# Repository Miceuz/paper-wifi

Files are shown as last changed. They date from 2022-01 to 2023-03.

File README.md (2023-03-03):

# Paper-WiFi

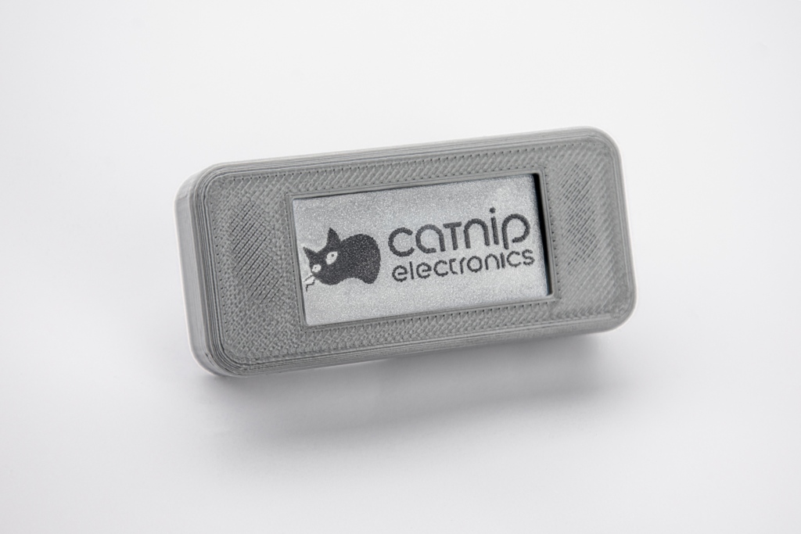
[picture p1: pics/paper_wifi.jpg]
Paper Wifi




Wifi-enabled e-paper display for I2C sensors. Arduino compatible software on Platformio. 3D printable case.

## Specifications

 * MCU: ESP32C3
 * Power supply: 2xAA, 3V
 * Sleep current: 38uA
 * Screen size: 2.13"
 * Display resolution: 212(H) × 104(V) pixels
 * Connectivity: I2C, UART over USB, UART
 * GPIO: 2 
 * Sensors: Temperature, Relative humidity
 * Temperature accuracy: 0.2°C typical
 * Relative humidity accuracy: 1.8% typical

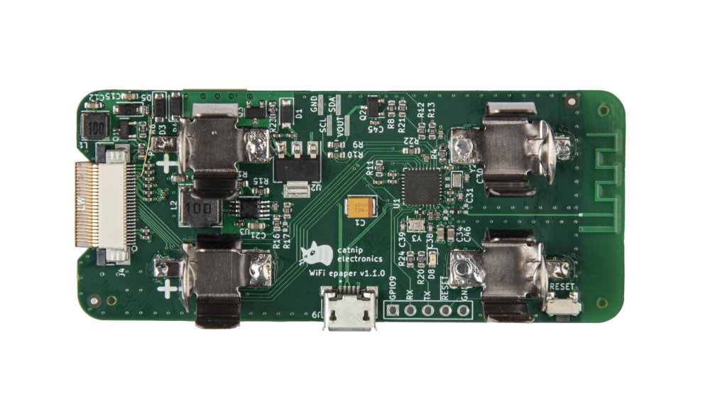
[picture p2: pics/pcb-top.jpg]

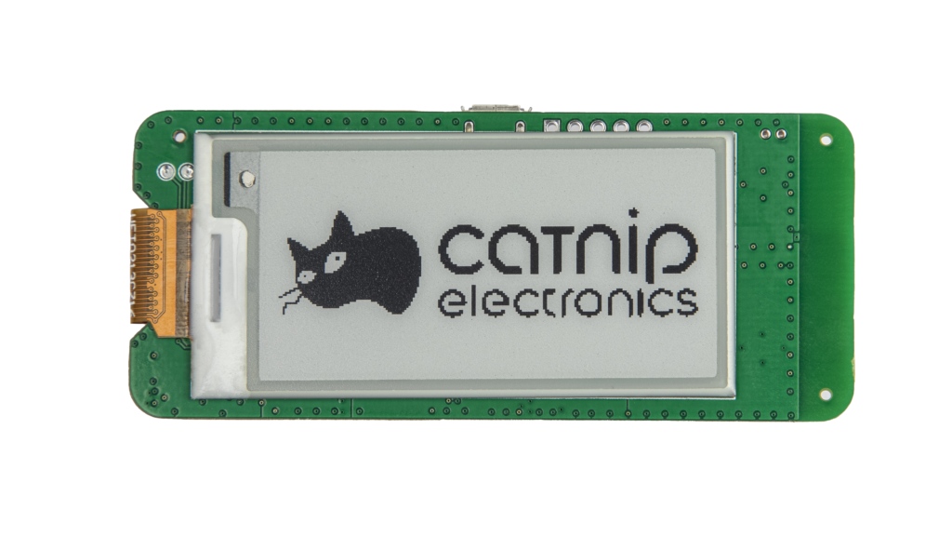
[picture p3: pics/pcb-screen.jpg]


## Programming instructions

Firmware build and upload process is managed by [Platformio](https://platformio.org). Most probably you will encounter the board in deep sleep in which it is not visible via USB. Jump GPIO9 to GND and reset the board to put it into bootloader mode. Run `pio run -t upload` to compile and upload firmware. Remove jumper and reset the board to run. If deep sleep is not used, board can be programmed without GPIO9 jumper.

## MQTT backend infrastructure

 * To quickly see your data piping in follow this guide: [Getting started with MQTT](https://github.com/Miceuz/paper-wifi/tree/main/tutorials/Getting%20started%20with%20MQTT)
 * To setup your own backend for data storage and display follow this guide: [docker-compose-mosquitto-influxdb-telegraf-grafana](https://github.com/Miceuz/docker-compose-mosquitto-influxdb-telegraf-grafana)

## Licence

[CERN Open Hardware Licence Version 2 - Strongly Reciprocal](https://ohwr.org/cern_ohl_s_v2.txt)

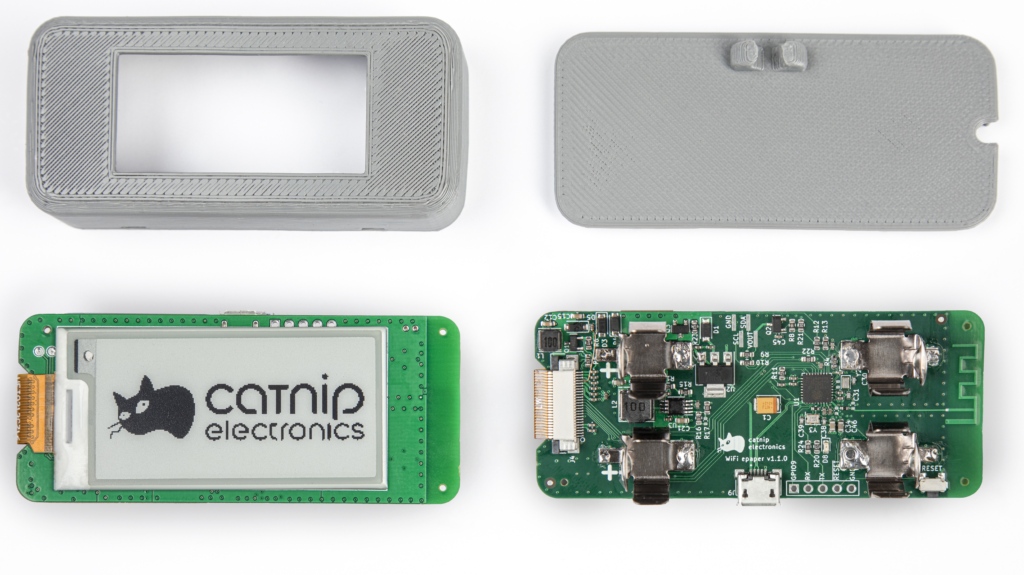
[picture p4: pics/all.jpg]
Paper Wifi internals


Open source
Made with KiCad
![Build with PlatformIO](https://img.shields.io/badge/build%20with-PlatformIO-orange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)


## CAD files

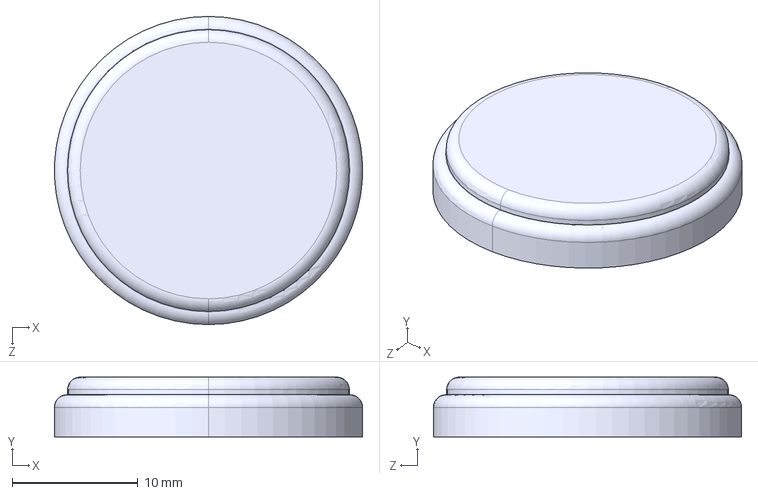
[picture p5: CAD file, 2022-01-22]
electronics/sensor-epaper/3d/User Library-CR 2450.STEP
24.5 x 4.75 x 24.5 mm

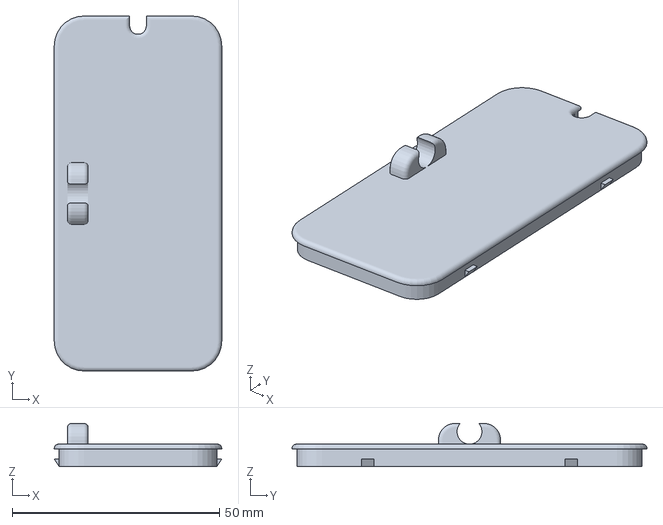
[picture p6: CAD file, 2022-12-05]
mechanical/enclosure-cover.3mf
40.4 x 85.6 x 10.4 mm

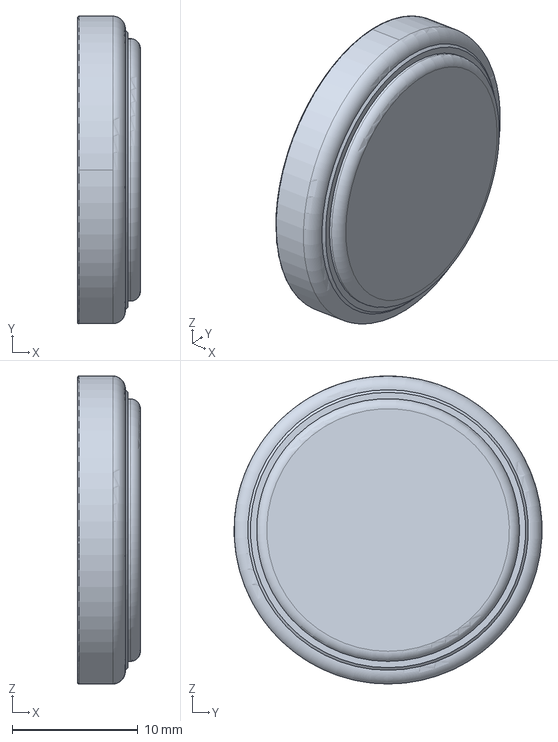
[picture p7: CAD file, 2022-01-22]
electronics/sensor-epaper/3d/battery-cr2450.stp
5.00 x 24.5 x 24.5 mm

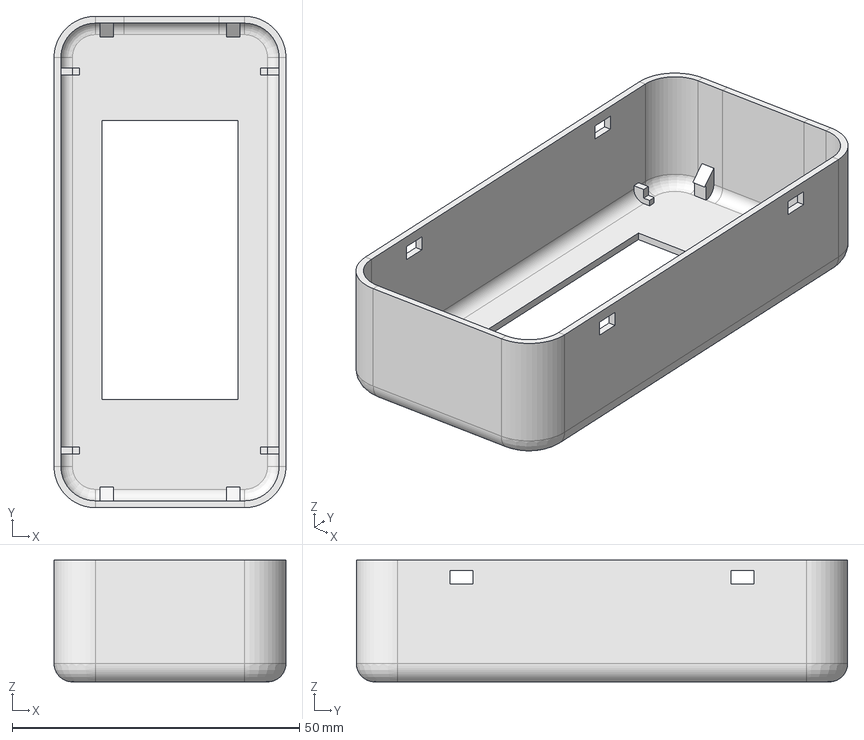
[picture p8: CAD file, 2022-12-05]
mechanical/enclosure.FCStd
40.4 x 85.6 x 21.2 mm

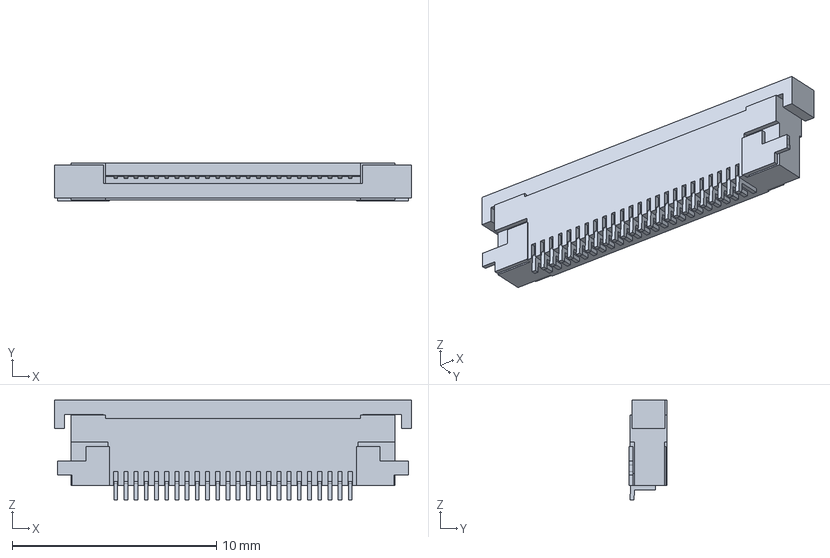
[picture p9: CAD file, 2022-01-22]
electronics/sensor-epaper/3d/ssfv24r_4stlf.stp
17.5 x 1.87 x 4.90 mm

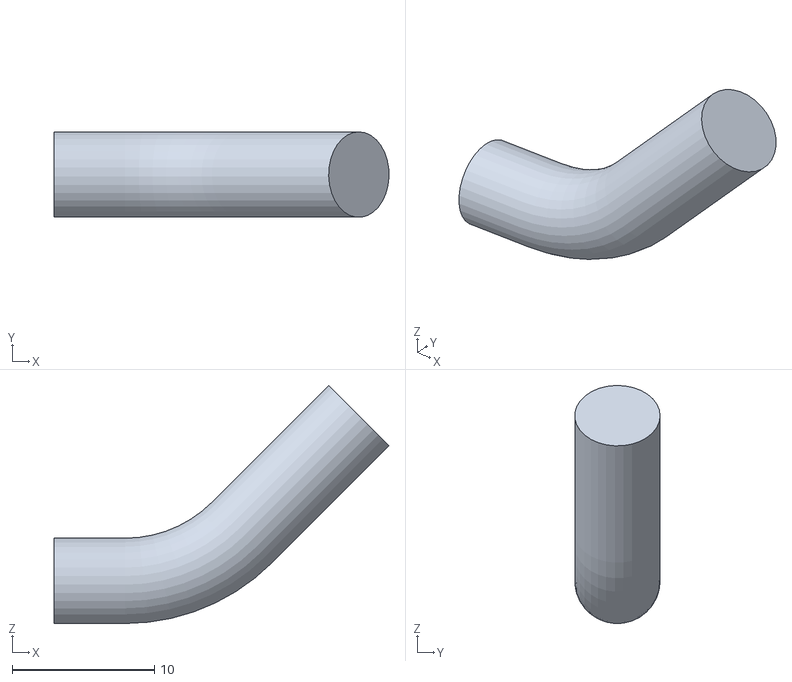
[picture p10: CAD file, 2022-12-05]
mechanical/enclosure-kronschtein.stl
23.5 x 5.99 x 16.7

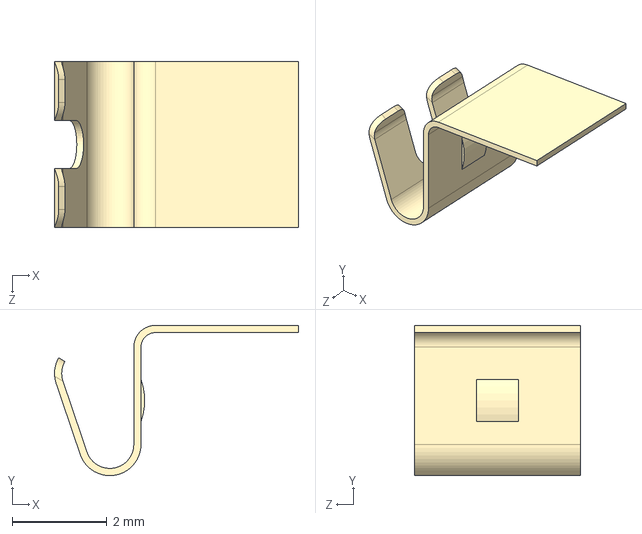
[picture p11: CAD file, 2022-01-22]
electronics/sensor-epaper/3d/keystone-PN110TR.STEP
5.16 x 3.17 x 3.51 mm

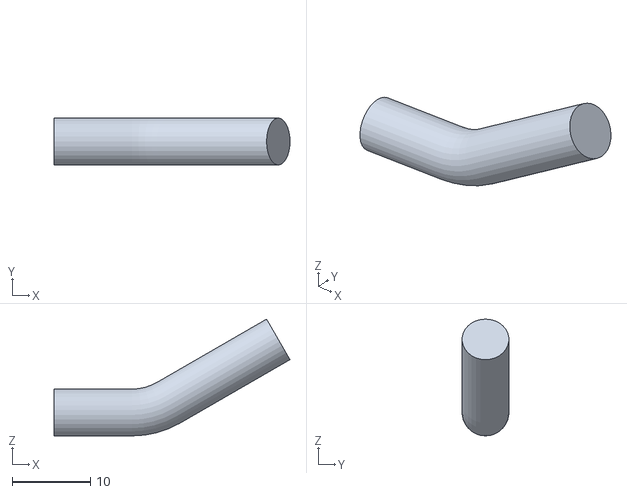
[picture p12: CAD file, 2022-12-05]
mechanical/enclosure-kronschtein1.stl
30.2 x 5.97 x 15.0

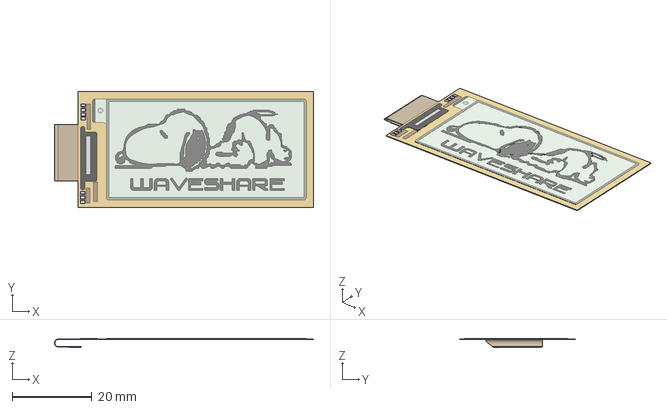
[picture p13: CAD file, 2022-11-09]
mechanical/Waveshare 2.13 (D) E-ink - Reverse Mount.stp
65.1 x 29.2 x 2.17 mm

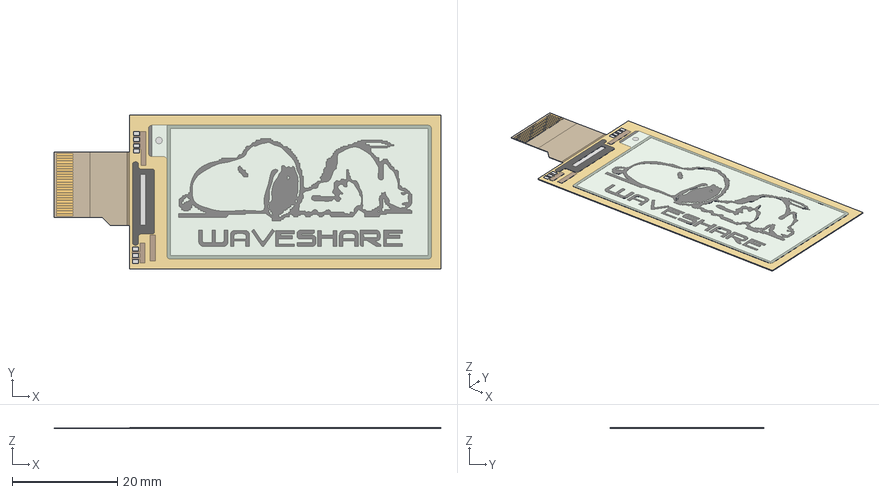
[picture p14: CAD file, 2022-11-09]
mechanical/Waveshare 2.13 (D) E-ink - Flat.stp
73.5 x 29.2 x 0.229 mm

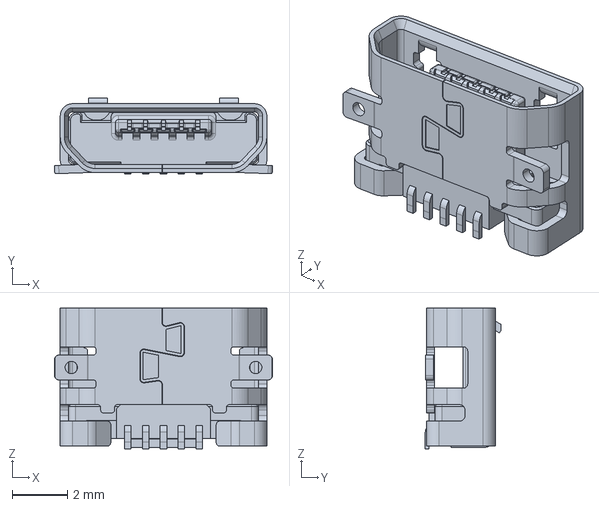
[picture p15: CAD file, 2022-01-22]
electronics/sensor-epaper/3d/10118192-002lfc.stp
7.91 x 2.77 x 5.10 mm

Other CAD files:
mechanical/enclosure-Body.3mf
mechanical/enclosure-Body.stl
mechanical/enclosure-cover.stl

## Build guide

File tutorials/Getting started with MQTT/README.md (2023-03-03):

# Getting your data via MQTT
This guide will allow you to see your data being sent via MQTT. Saving data to databases and displaying graphs is another story, but here we will concentrate on getting MQTT running.

## Listening to MQTT messages on your browser 
Open this page on your browser: http://www.emqx.io/online-mqtt-client

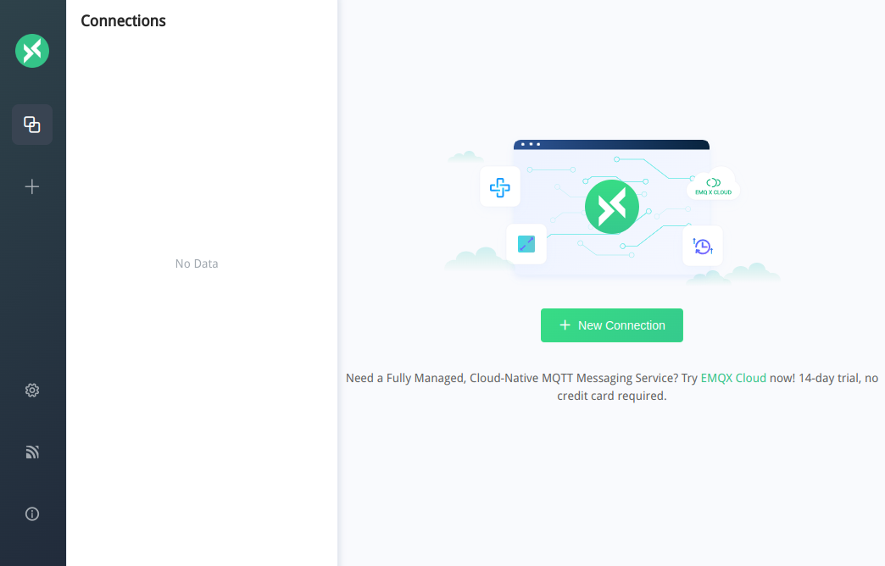
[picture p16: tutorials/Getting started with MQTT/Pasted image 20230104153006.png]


Click **New Connection** and make sure you enter these data and click **Connect**:

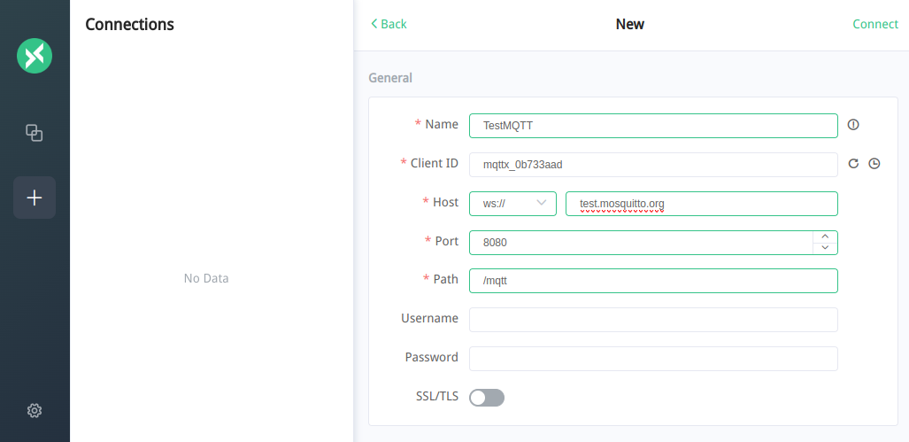
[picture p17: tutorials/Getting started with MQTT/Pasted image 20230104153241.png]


In the newly opened interface click **New Subscription** 

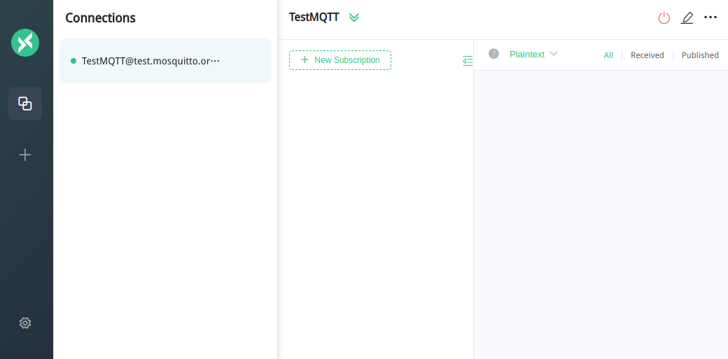
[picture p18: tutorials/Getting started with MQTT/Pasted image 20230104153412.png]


Enter *paper_wifi/test/#* as a topic name and click **Confirm**

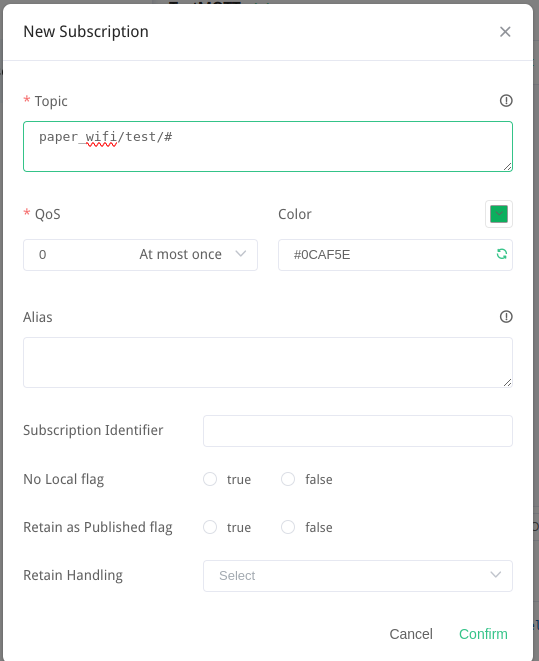
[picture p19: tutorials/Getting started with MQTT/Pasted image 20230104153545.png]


Now you are ready to receive MQTT messages!

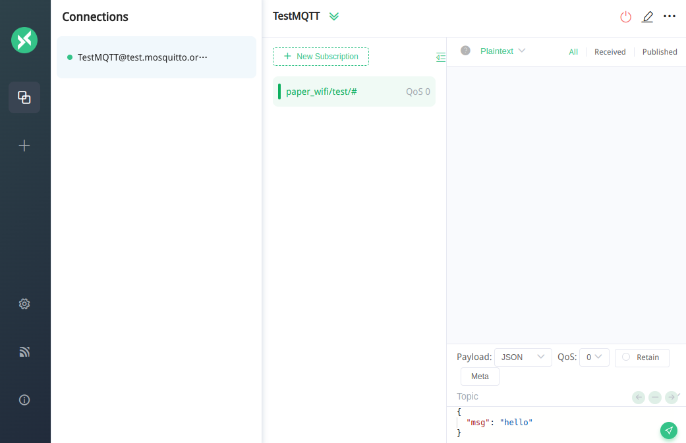
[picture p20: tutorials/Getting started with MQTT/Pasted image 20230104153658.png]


Once your Paper WiFi starts transmitting you'll see messages posted in this interface:

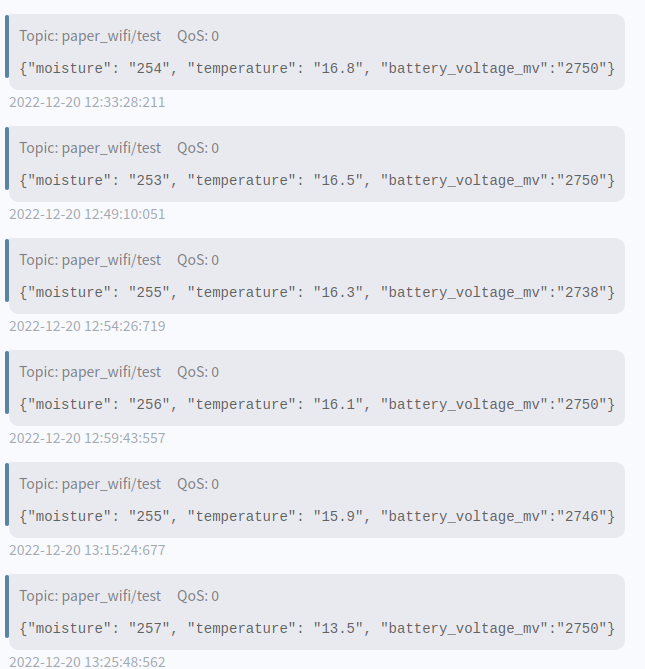
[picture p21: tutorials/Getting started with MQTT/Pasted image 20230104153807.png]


## Listening for MQTT messages on your phone 

I liked an app called *MQTT Dash*, but you can choose another one. The setup procedure will be similar for any app of the type.

Specify settings outlined below to set up connection to the MQTT broker server.

You can set up several widgets for your data that look like this:

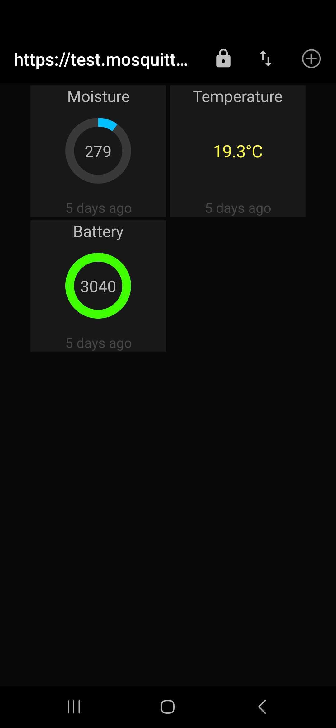
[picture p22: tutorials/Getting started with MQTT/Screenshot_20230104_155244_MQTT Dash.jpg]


To set up a widget note the format of how it's specified:

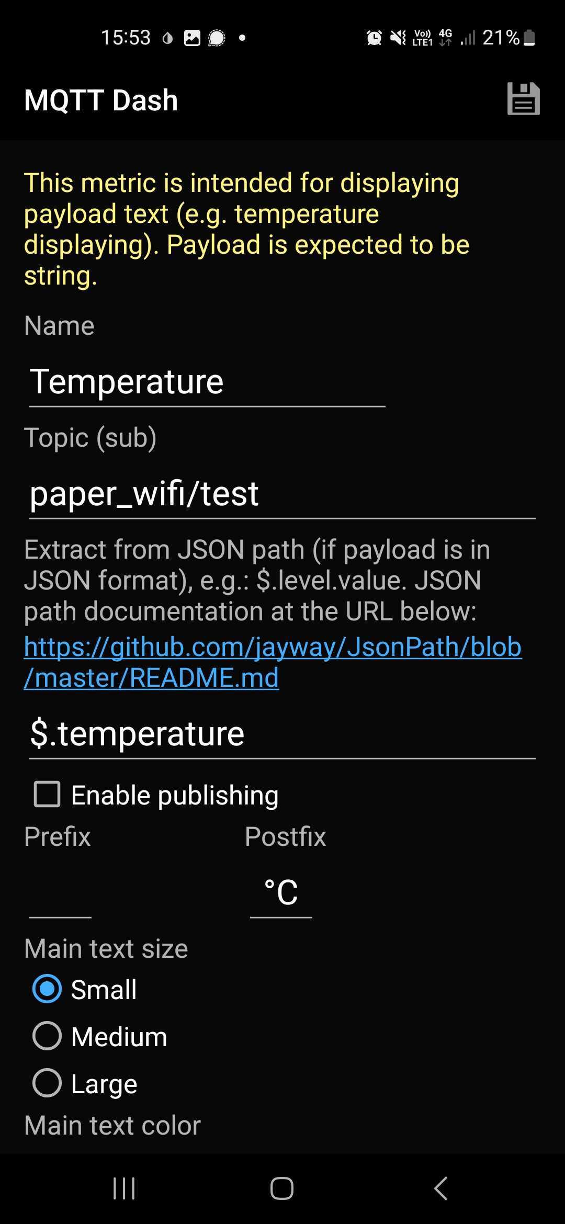
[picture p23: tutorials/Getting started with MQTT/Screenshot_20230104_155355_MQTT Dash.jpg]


## Configuring MQTT on your Paper wifi

MQTT is configured out of the box in the demo firmware, setting these parameters:

| Setting | Value |
| --- | --- |
| MQTT Broker Address | test.mosquitto.org |
| MQTT Broker Port | 1883 |
| MQTT username | _empty_ |
| MQTT password | _empty_ |
| MQTT topic | paper_wifi/test |

Reset your Paper WiFi board to enter WiFi setup, then connect to it via WiFi. 

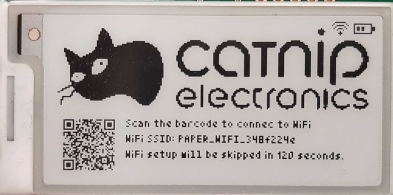
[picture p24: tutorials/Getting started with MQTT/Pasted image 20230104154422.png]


Your PC or smartphone should suggest you to open "router configuration" or "captive portal" if it doesn't, open url http://4.3.2.1 to see the configuration page:

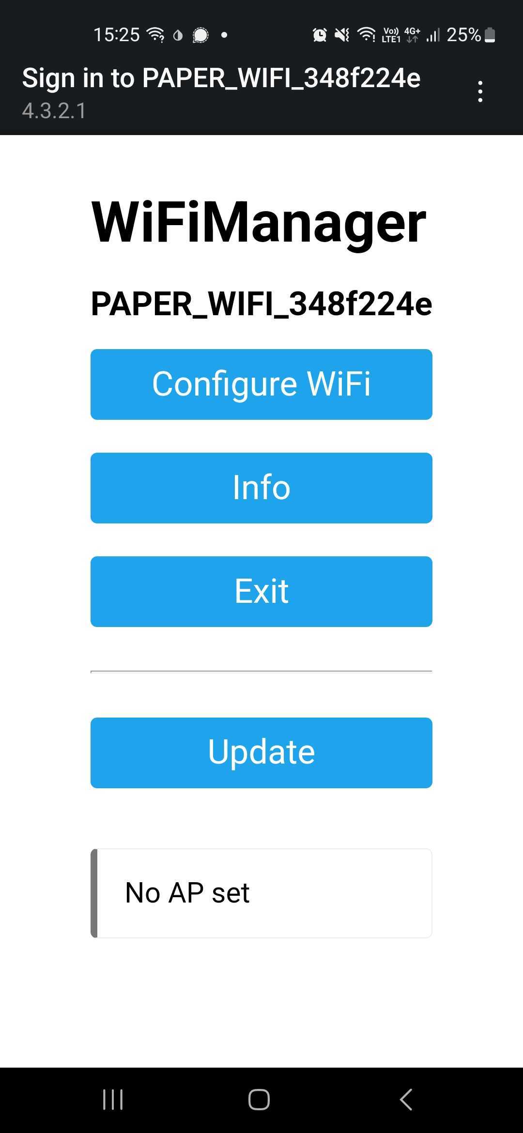
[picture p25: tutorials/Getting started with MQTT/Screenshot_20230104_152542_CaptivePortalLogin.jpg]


Click **Configure WiFi**. The next page will show you a list of WiFi networks visible to the board. Select your network and specify the password for it.

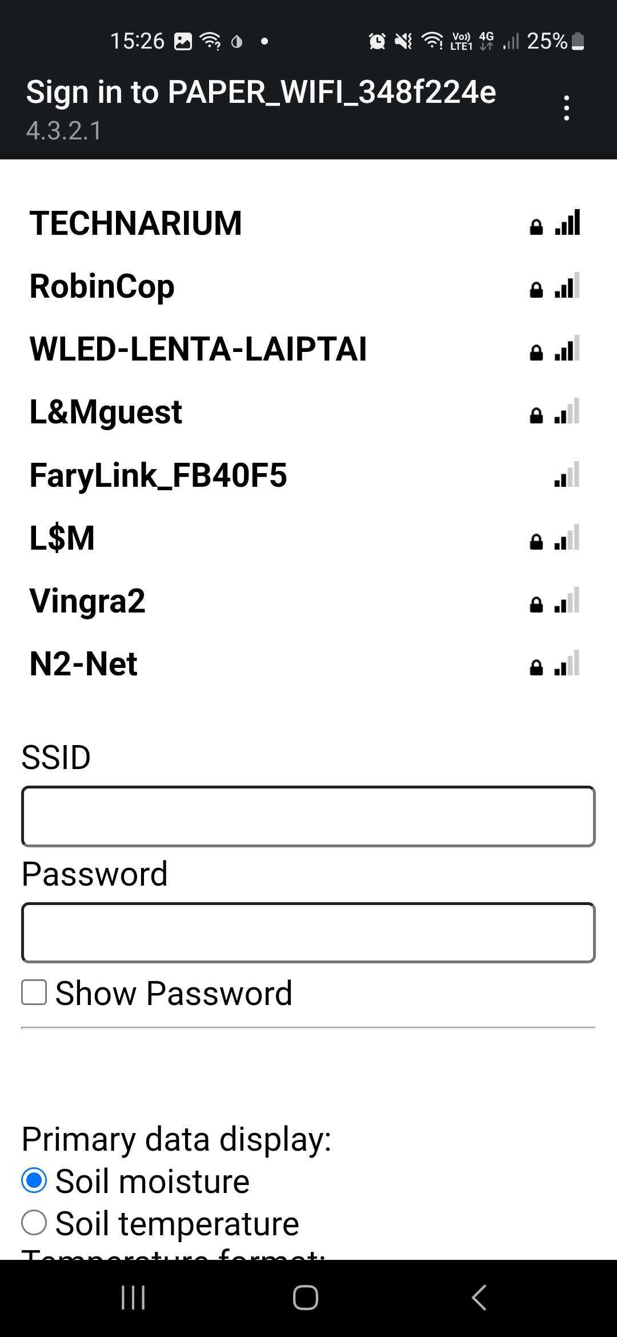
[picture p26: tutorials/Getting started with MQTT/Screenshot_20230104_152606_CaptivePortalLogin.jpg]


Lower on the same page you'll see MQTT patameters mentioned above:

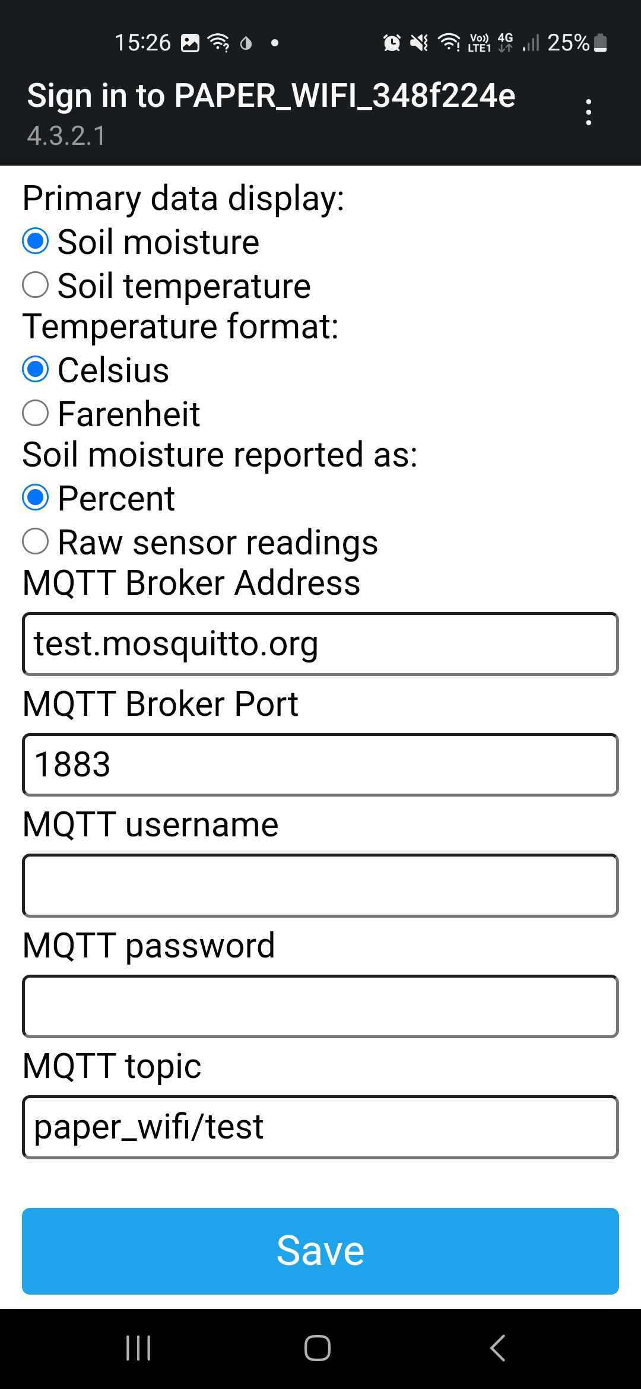
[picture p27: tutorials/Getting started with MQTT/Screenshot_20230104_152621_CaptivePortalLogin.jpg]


Don't touch them for now as that's exactly what you have configured in your MQTT client. Click **Save** and wait for a few moments for the board to connect to your WiFi, make measurements and send them via MQTT. You should be seeing values comming in MQTT client app. 

Note, that the board is configured to send measurements once in 5 minutes, also it won't send a measurement and update display if measurements didn't change from previous measurement.

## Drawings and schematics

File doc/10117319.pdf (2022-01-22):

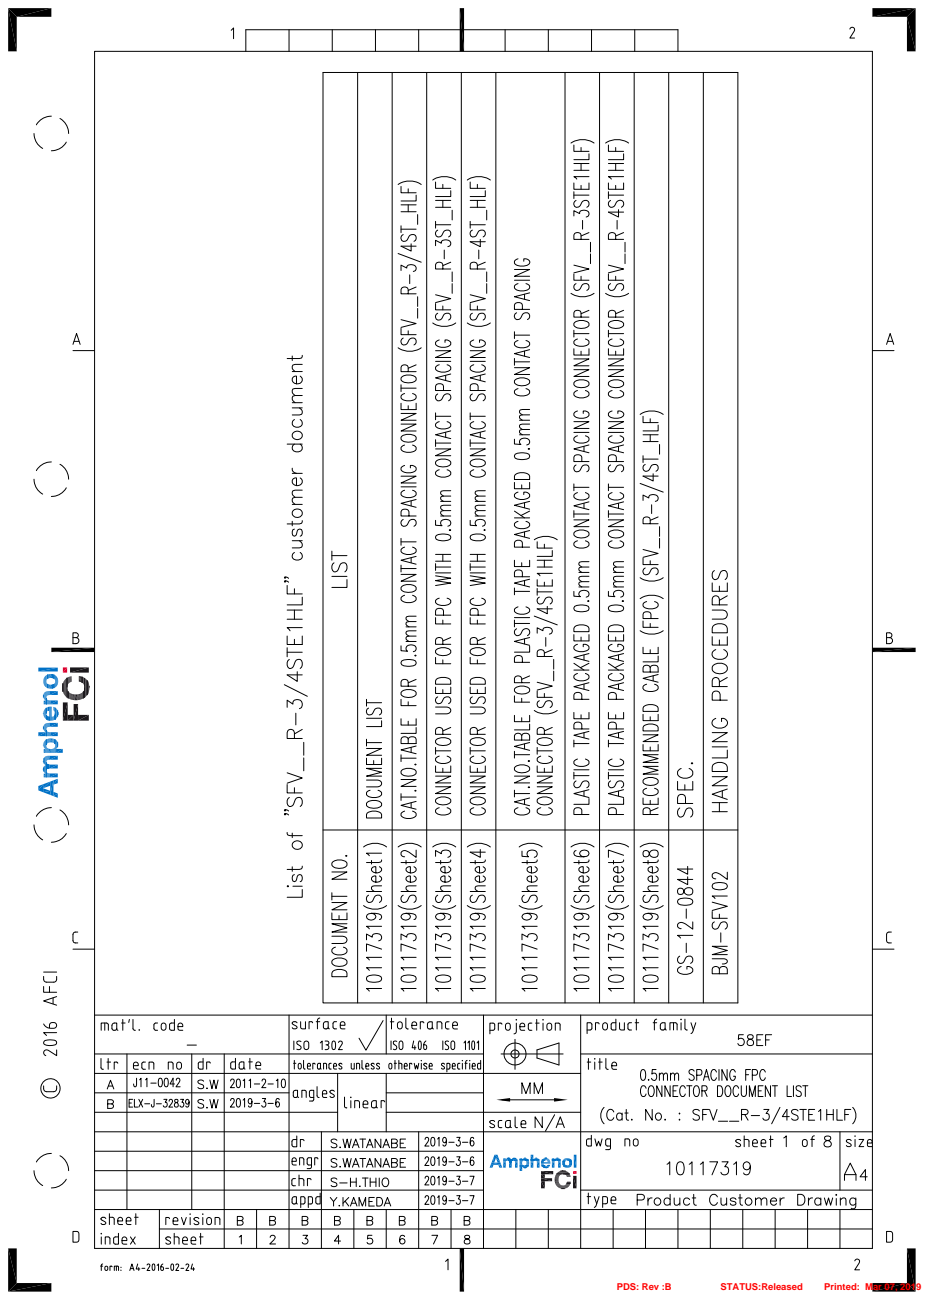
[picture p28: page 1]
PDS: Rev :B; STATUS:Released; Printed: Mar 07, 2019

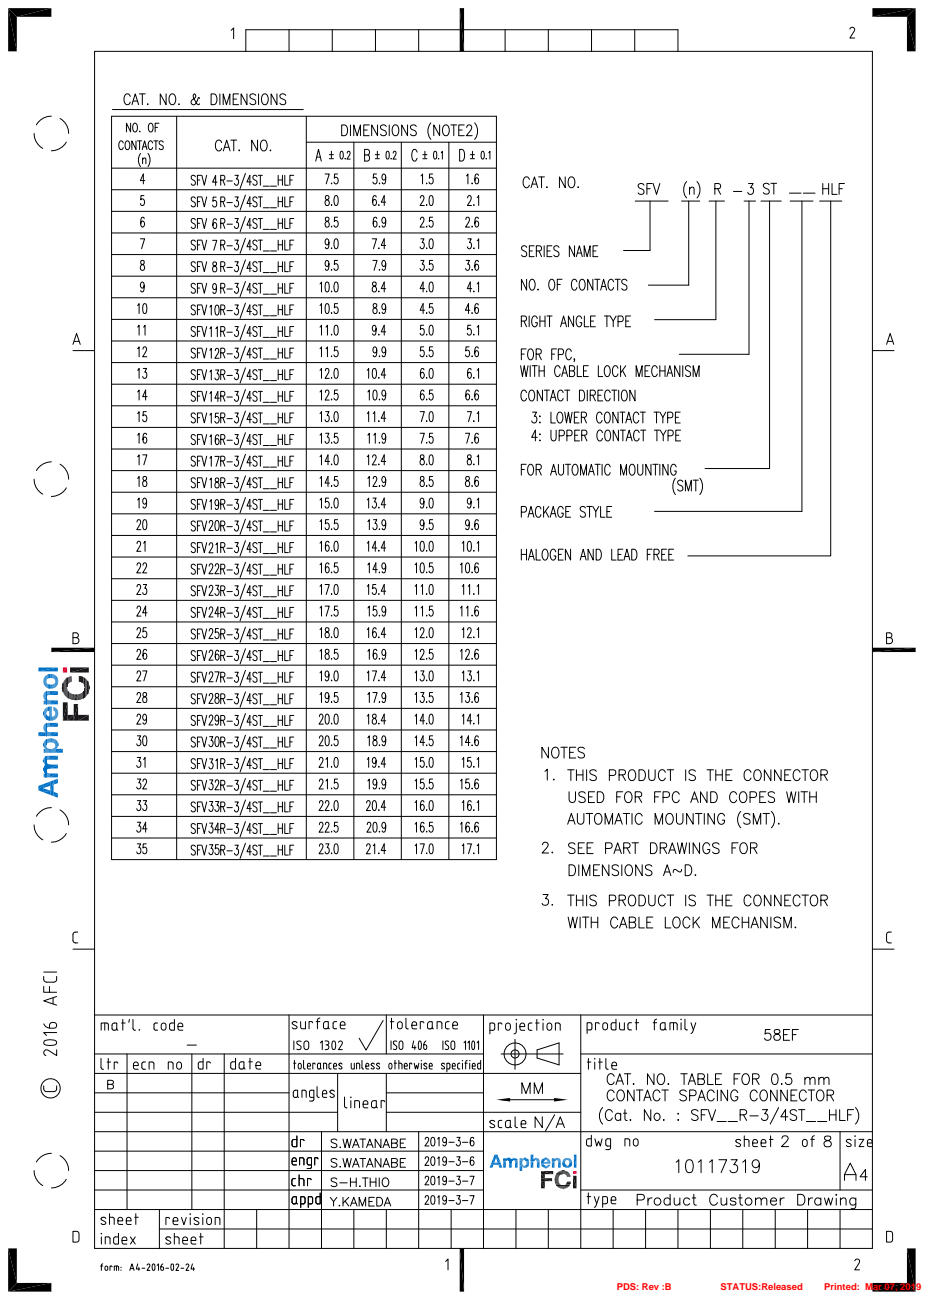
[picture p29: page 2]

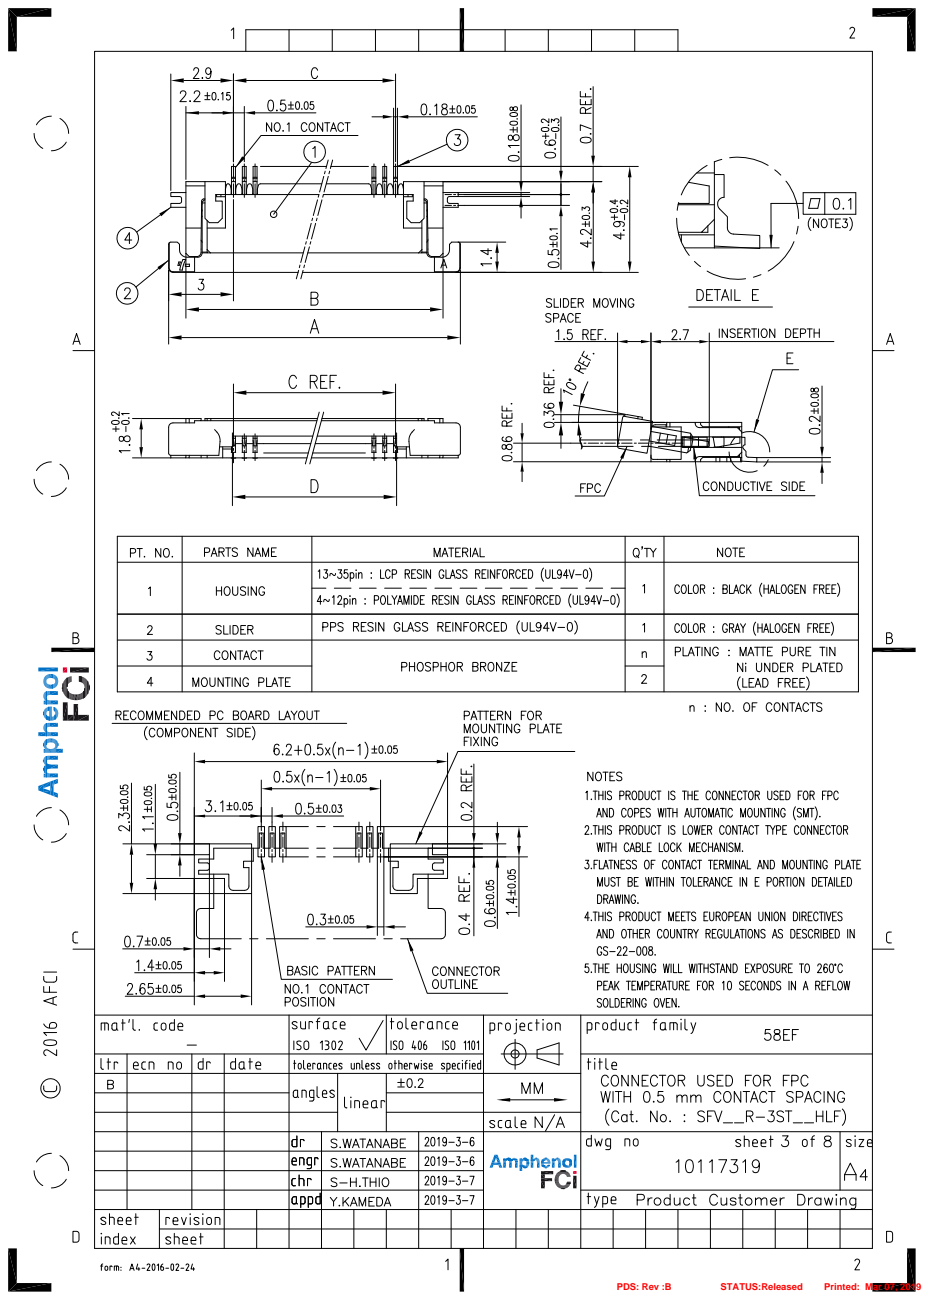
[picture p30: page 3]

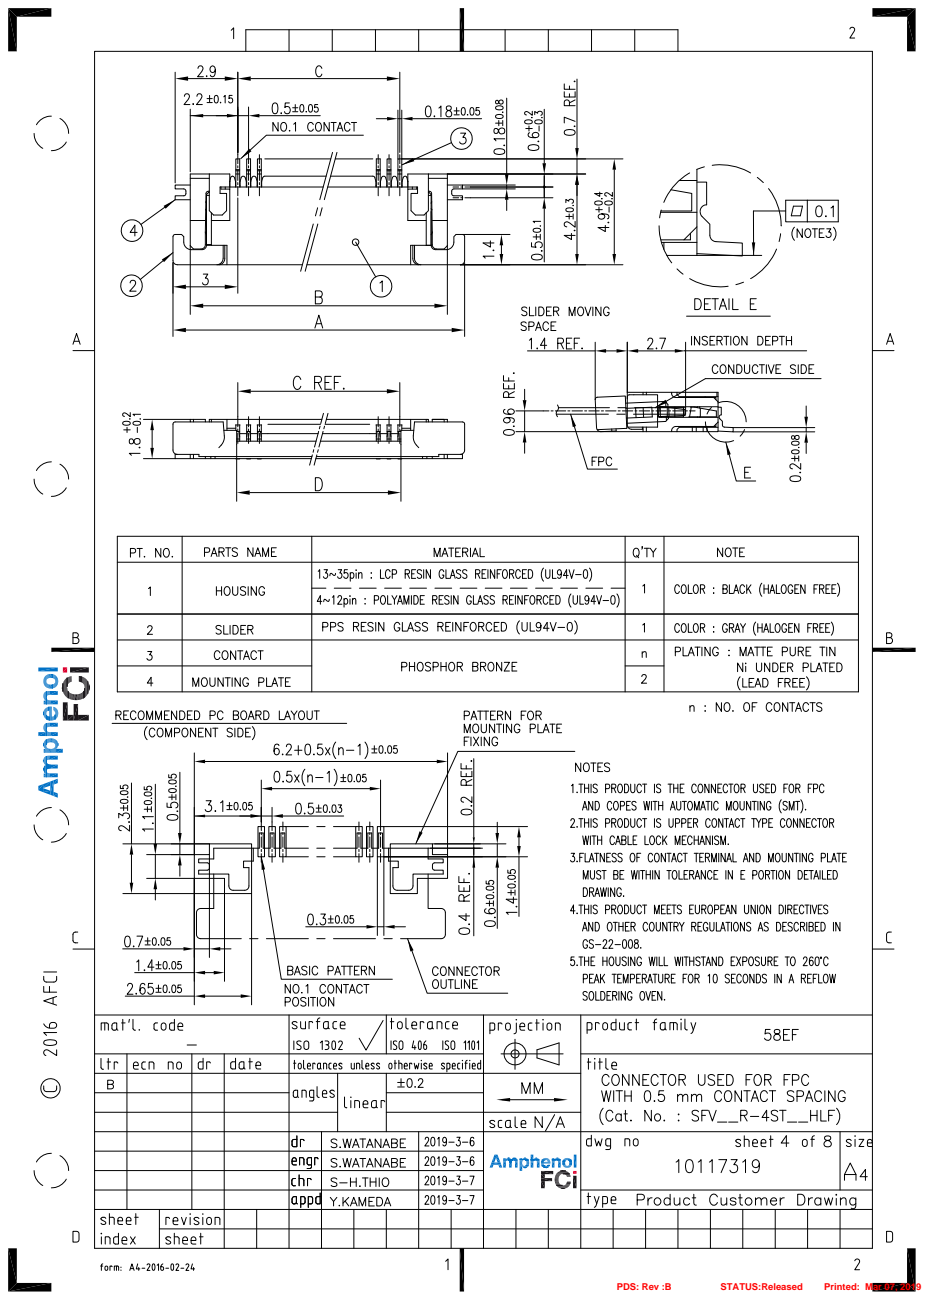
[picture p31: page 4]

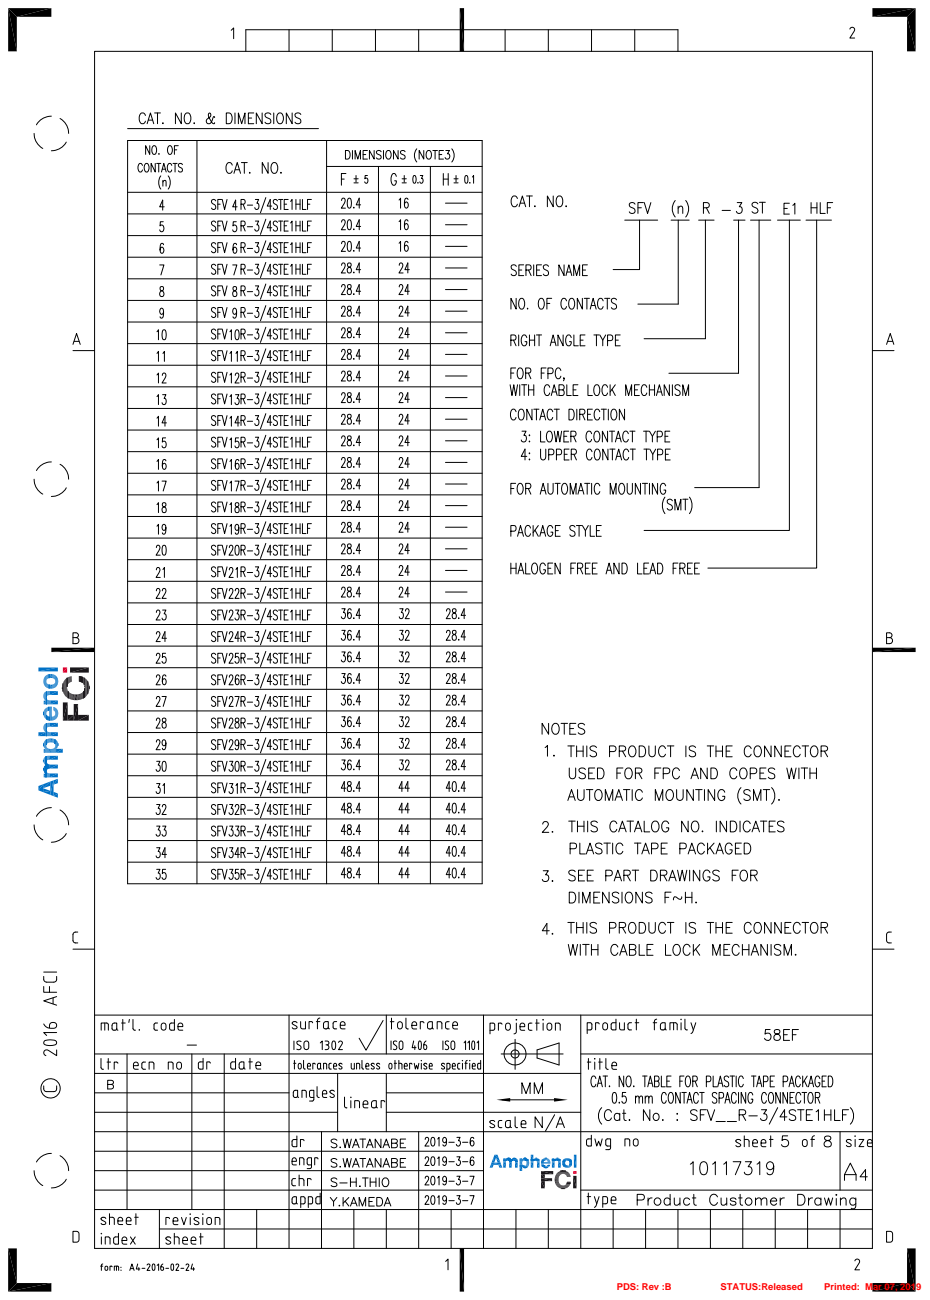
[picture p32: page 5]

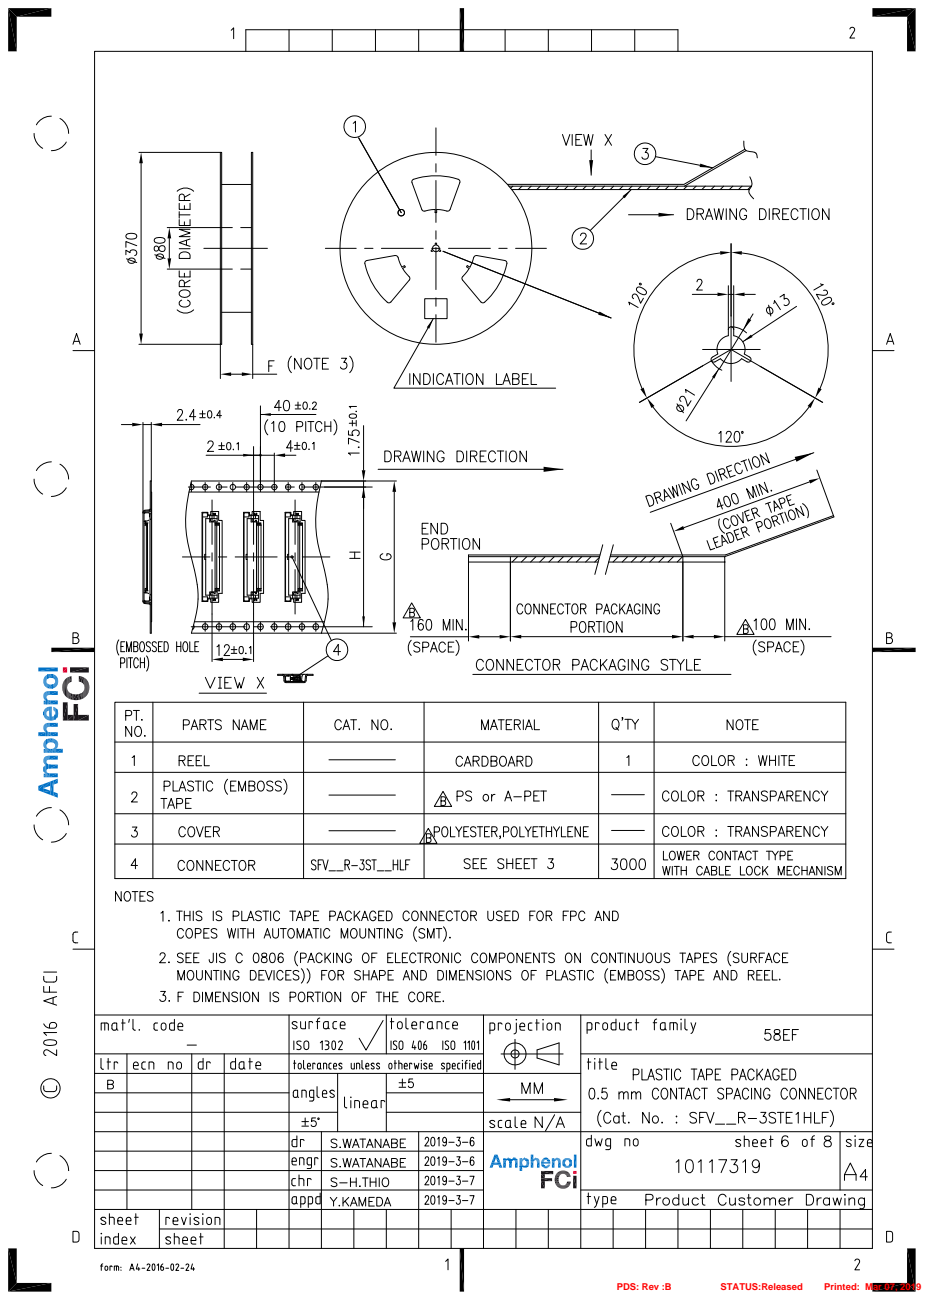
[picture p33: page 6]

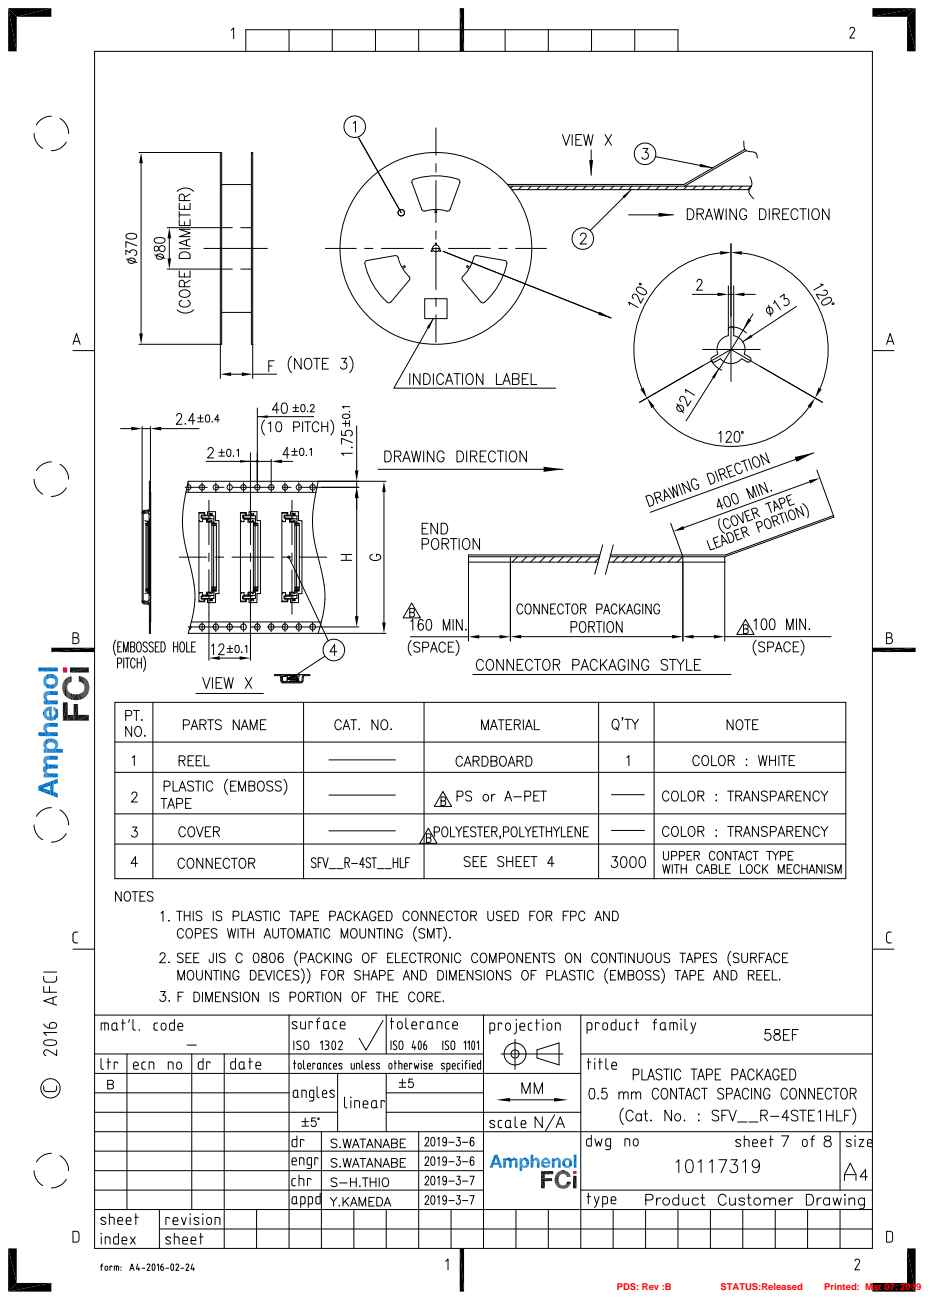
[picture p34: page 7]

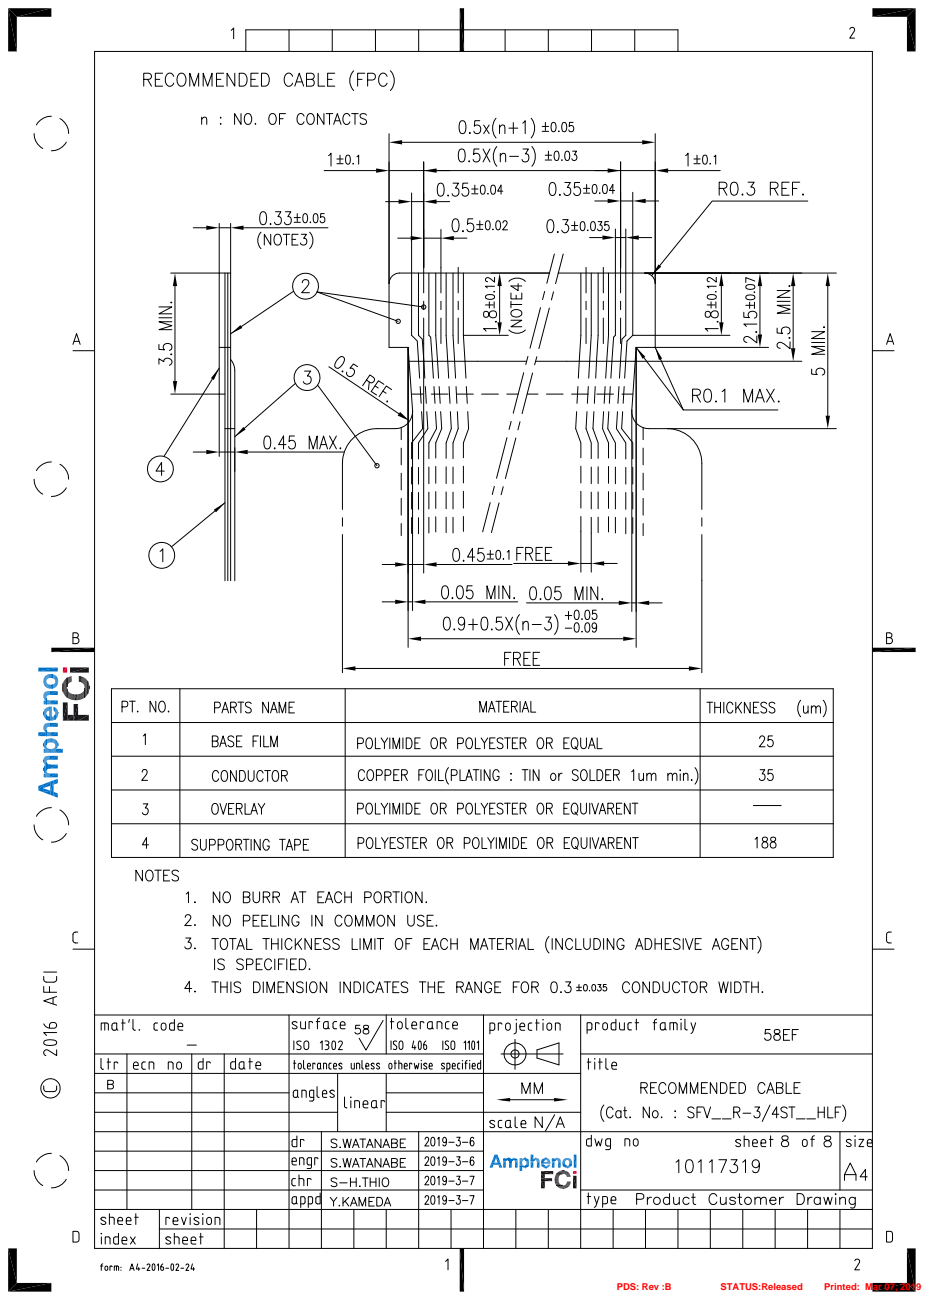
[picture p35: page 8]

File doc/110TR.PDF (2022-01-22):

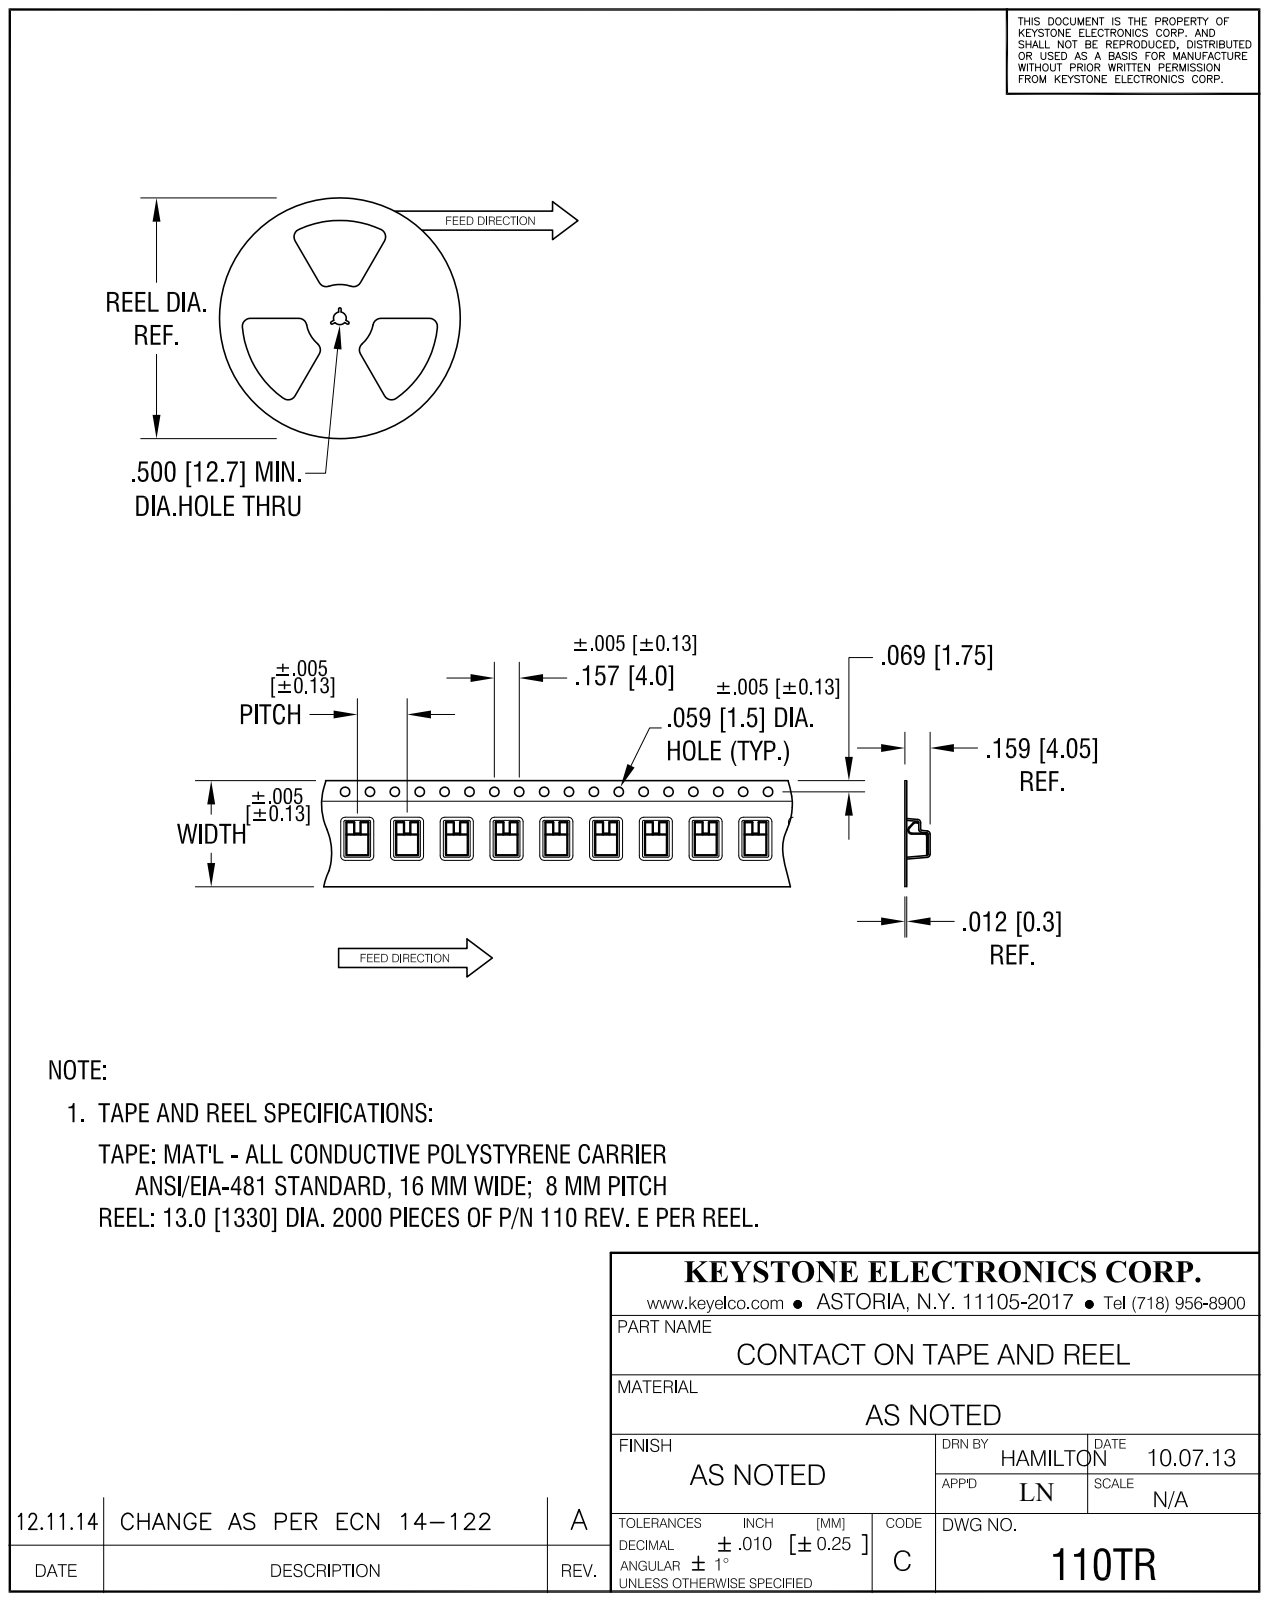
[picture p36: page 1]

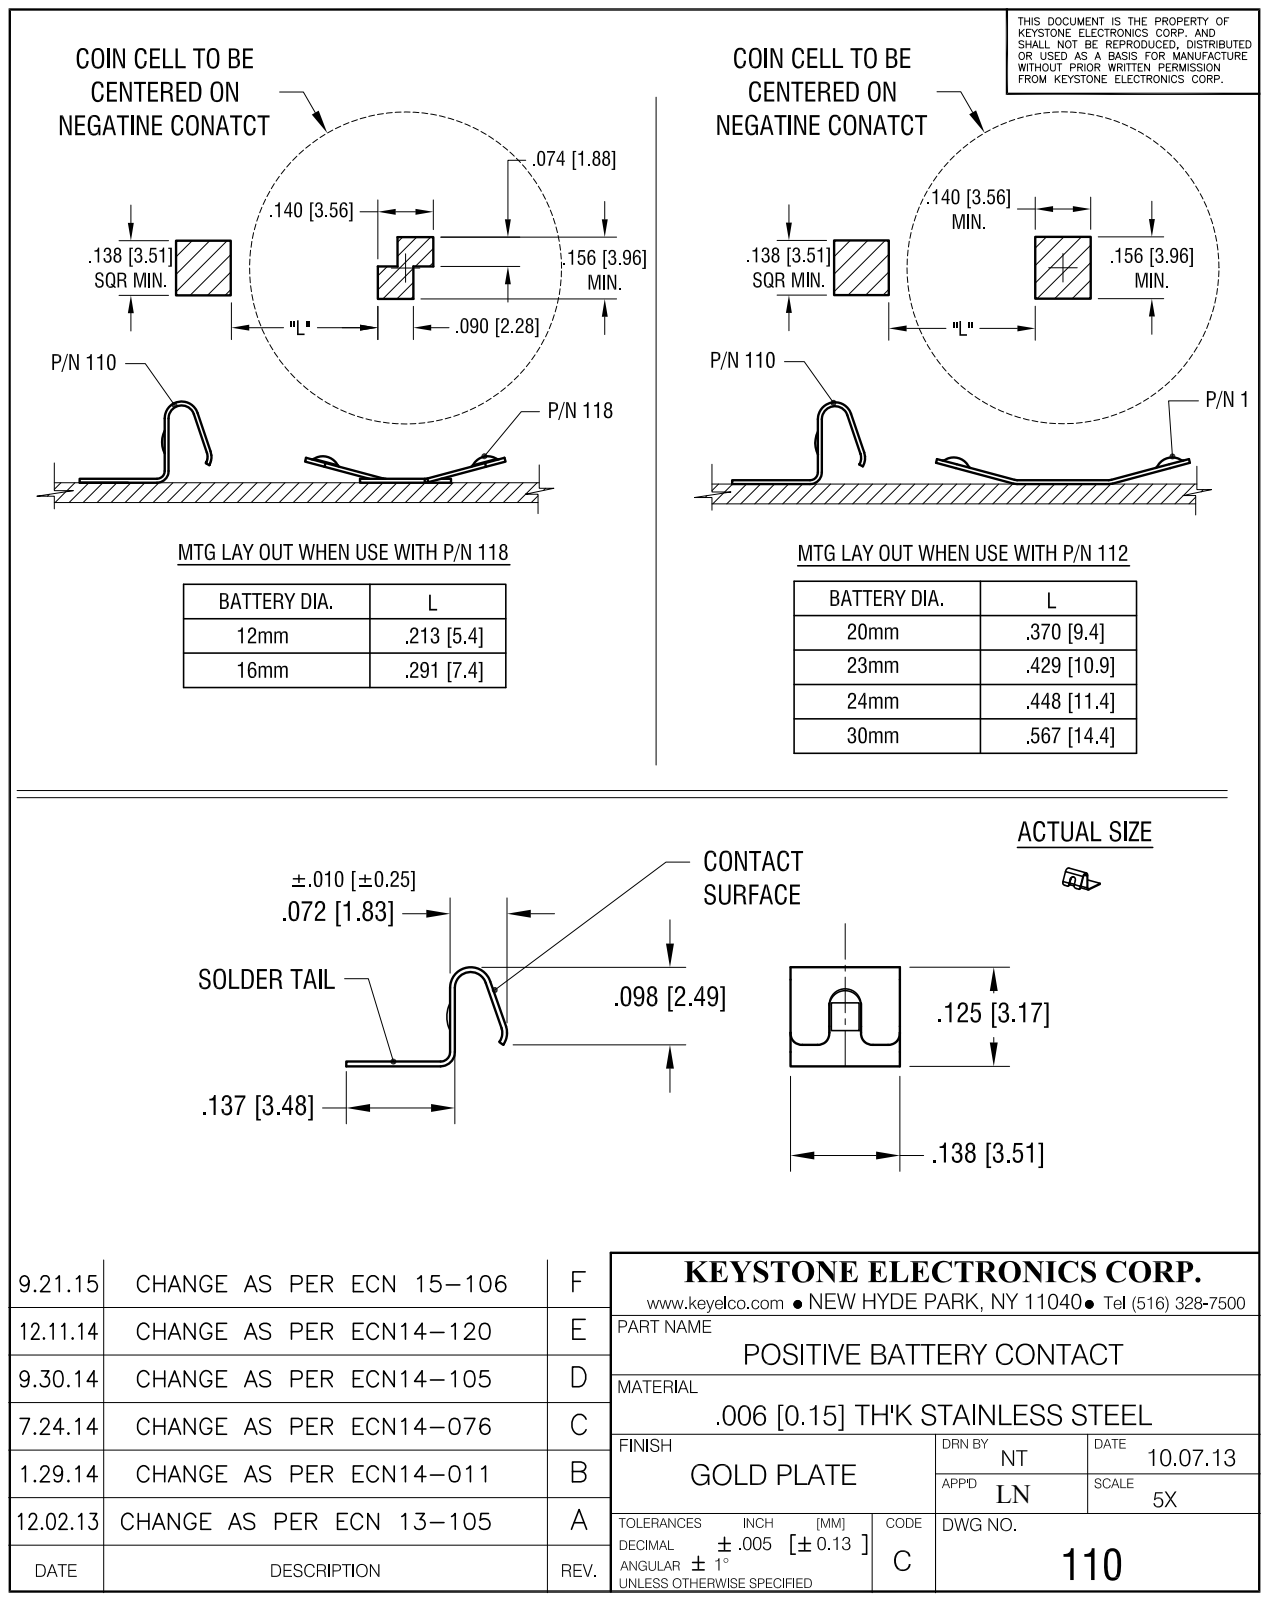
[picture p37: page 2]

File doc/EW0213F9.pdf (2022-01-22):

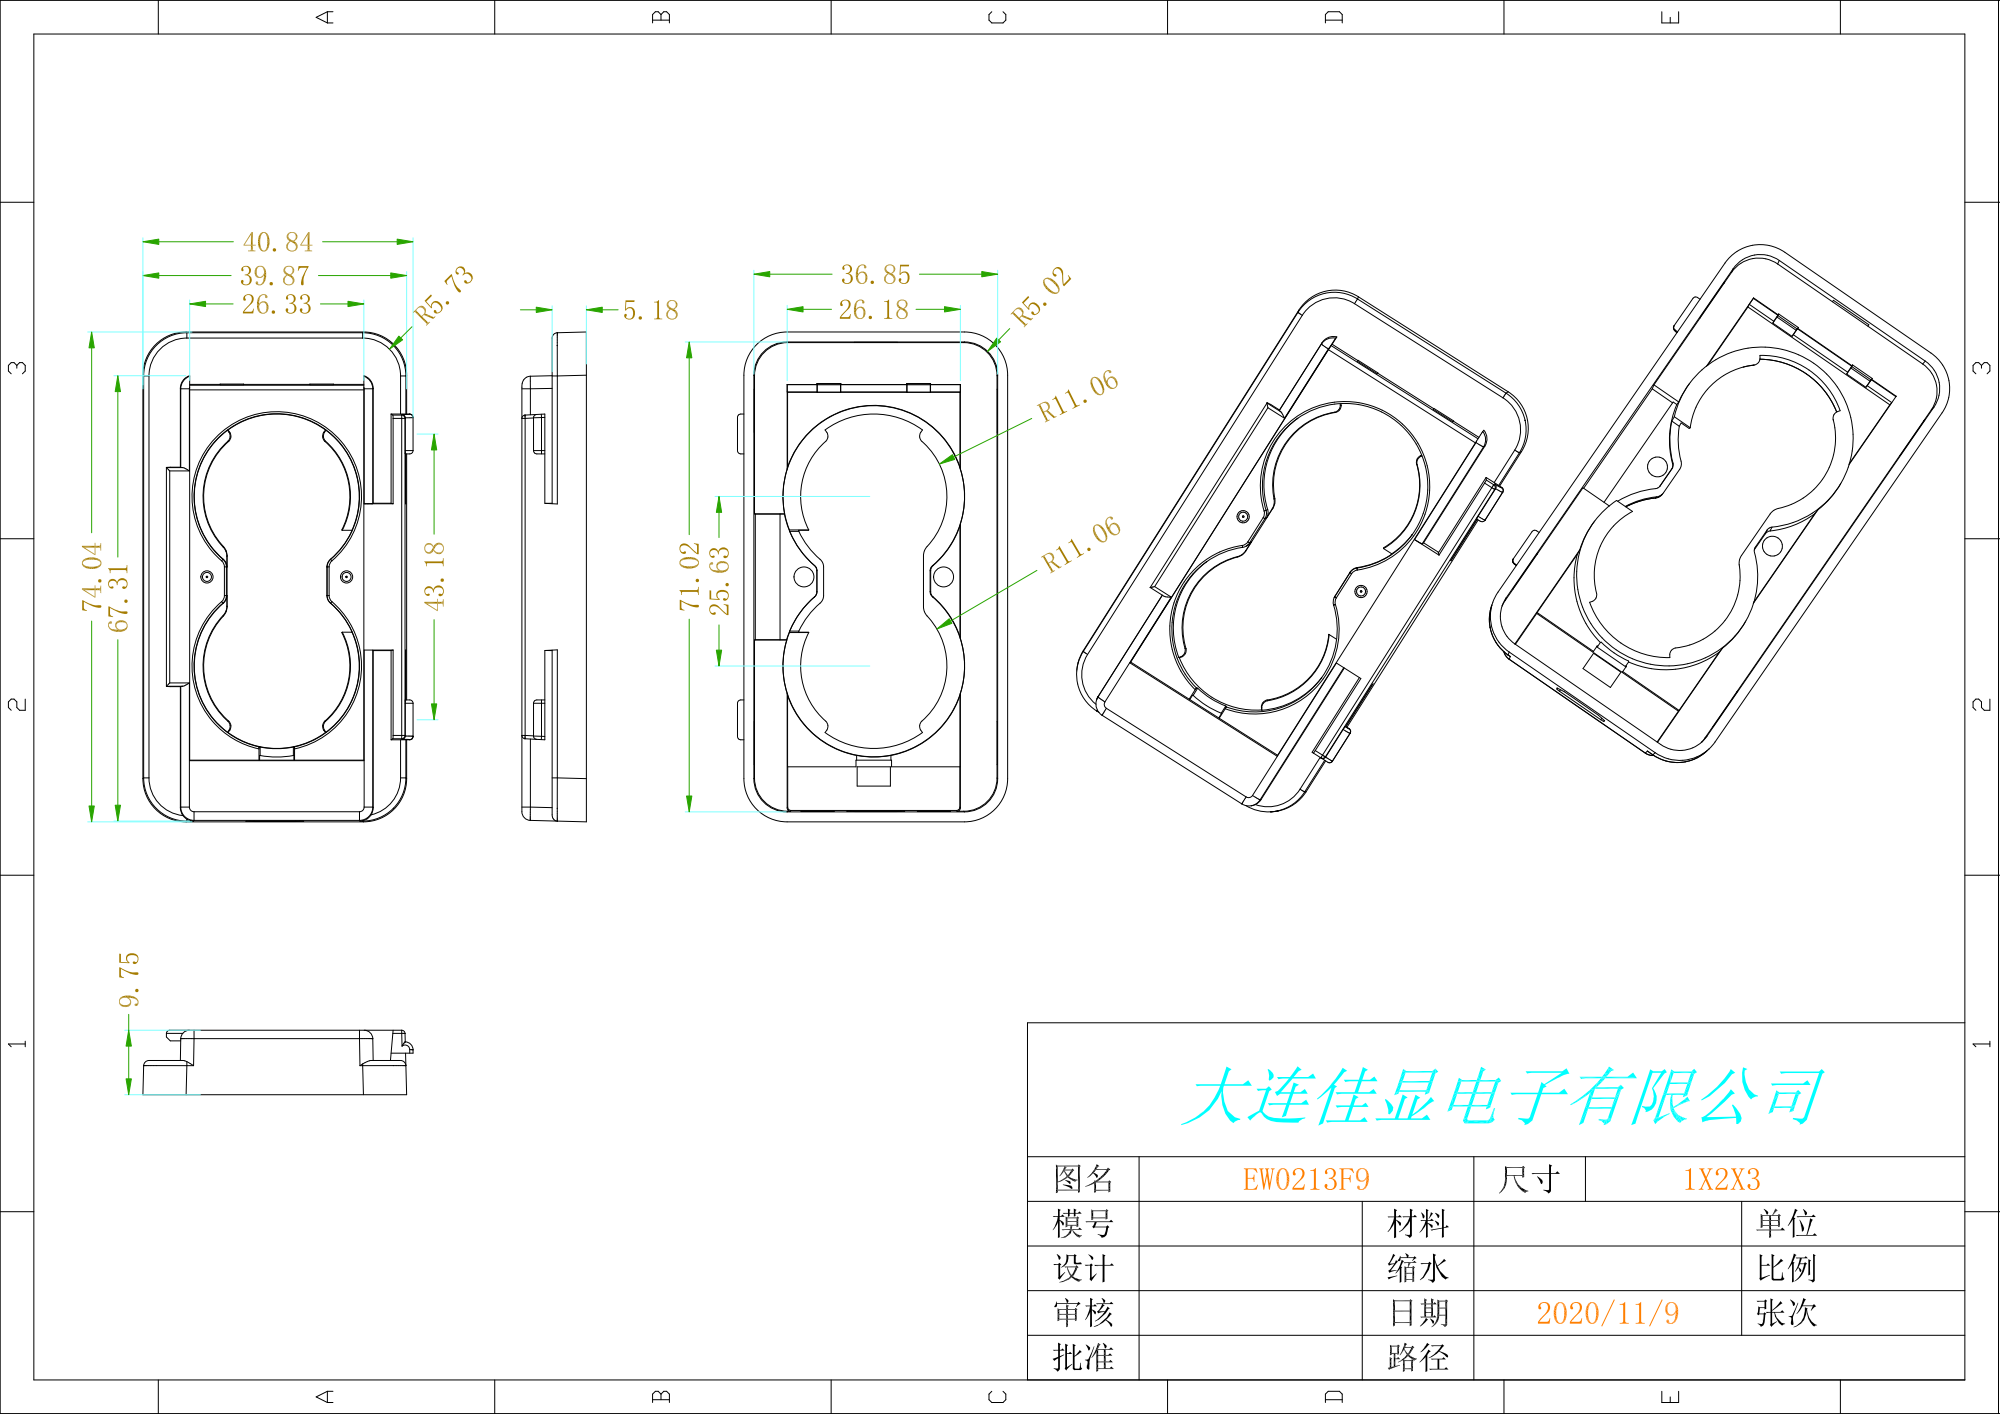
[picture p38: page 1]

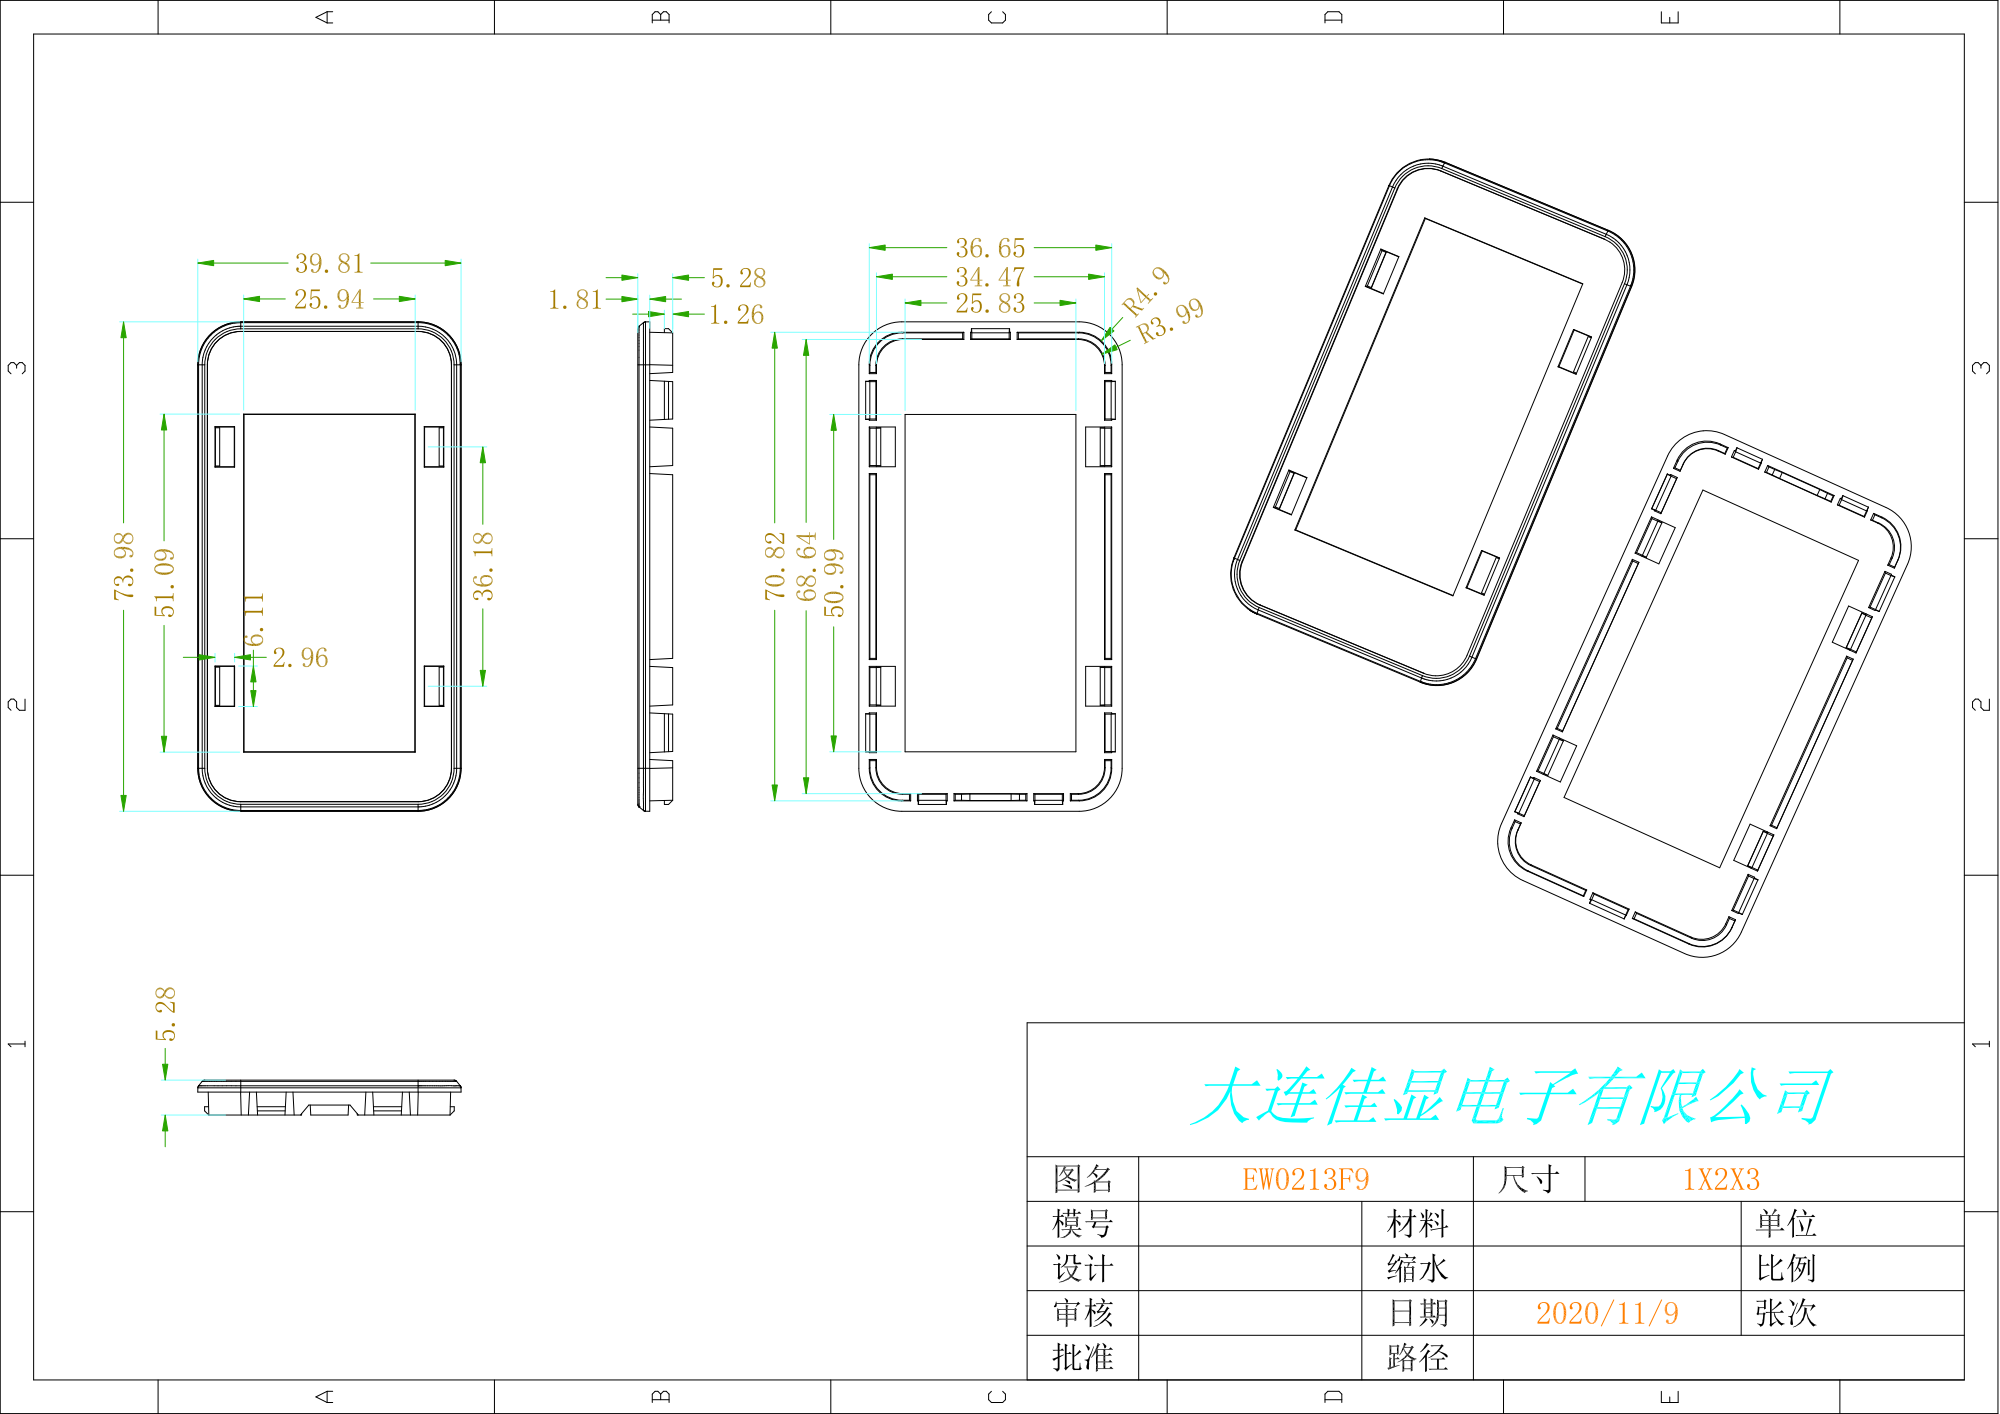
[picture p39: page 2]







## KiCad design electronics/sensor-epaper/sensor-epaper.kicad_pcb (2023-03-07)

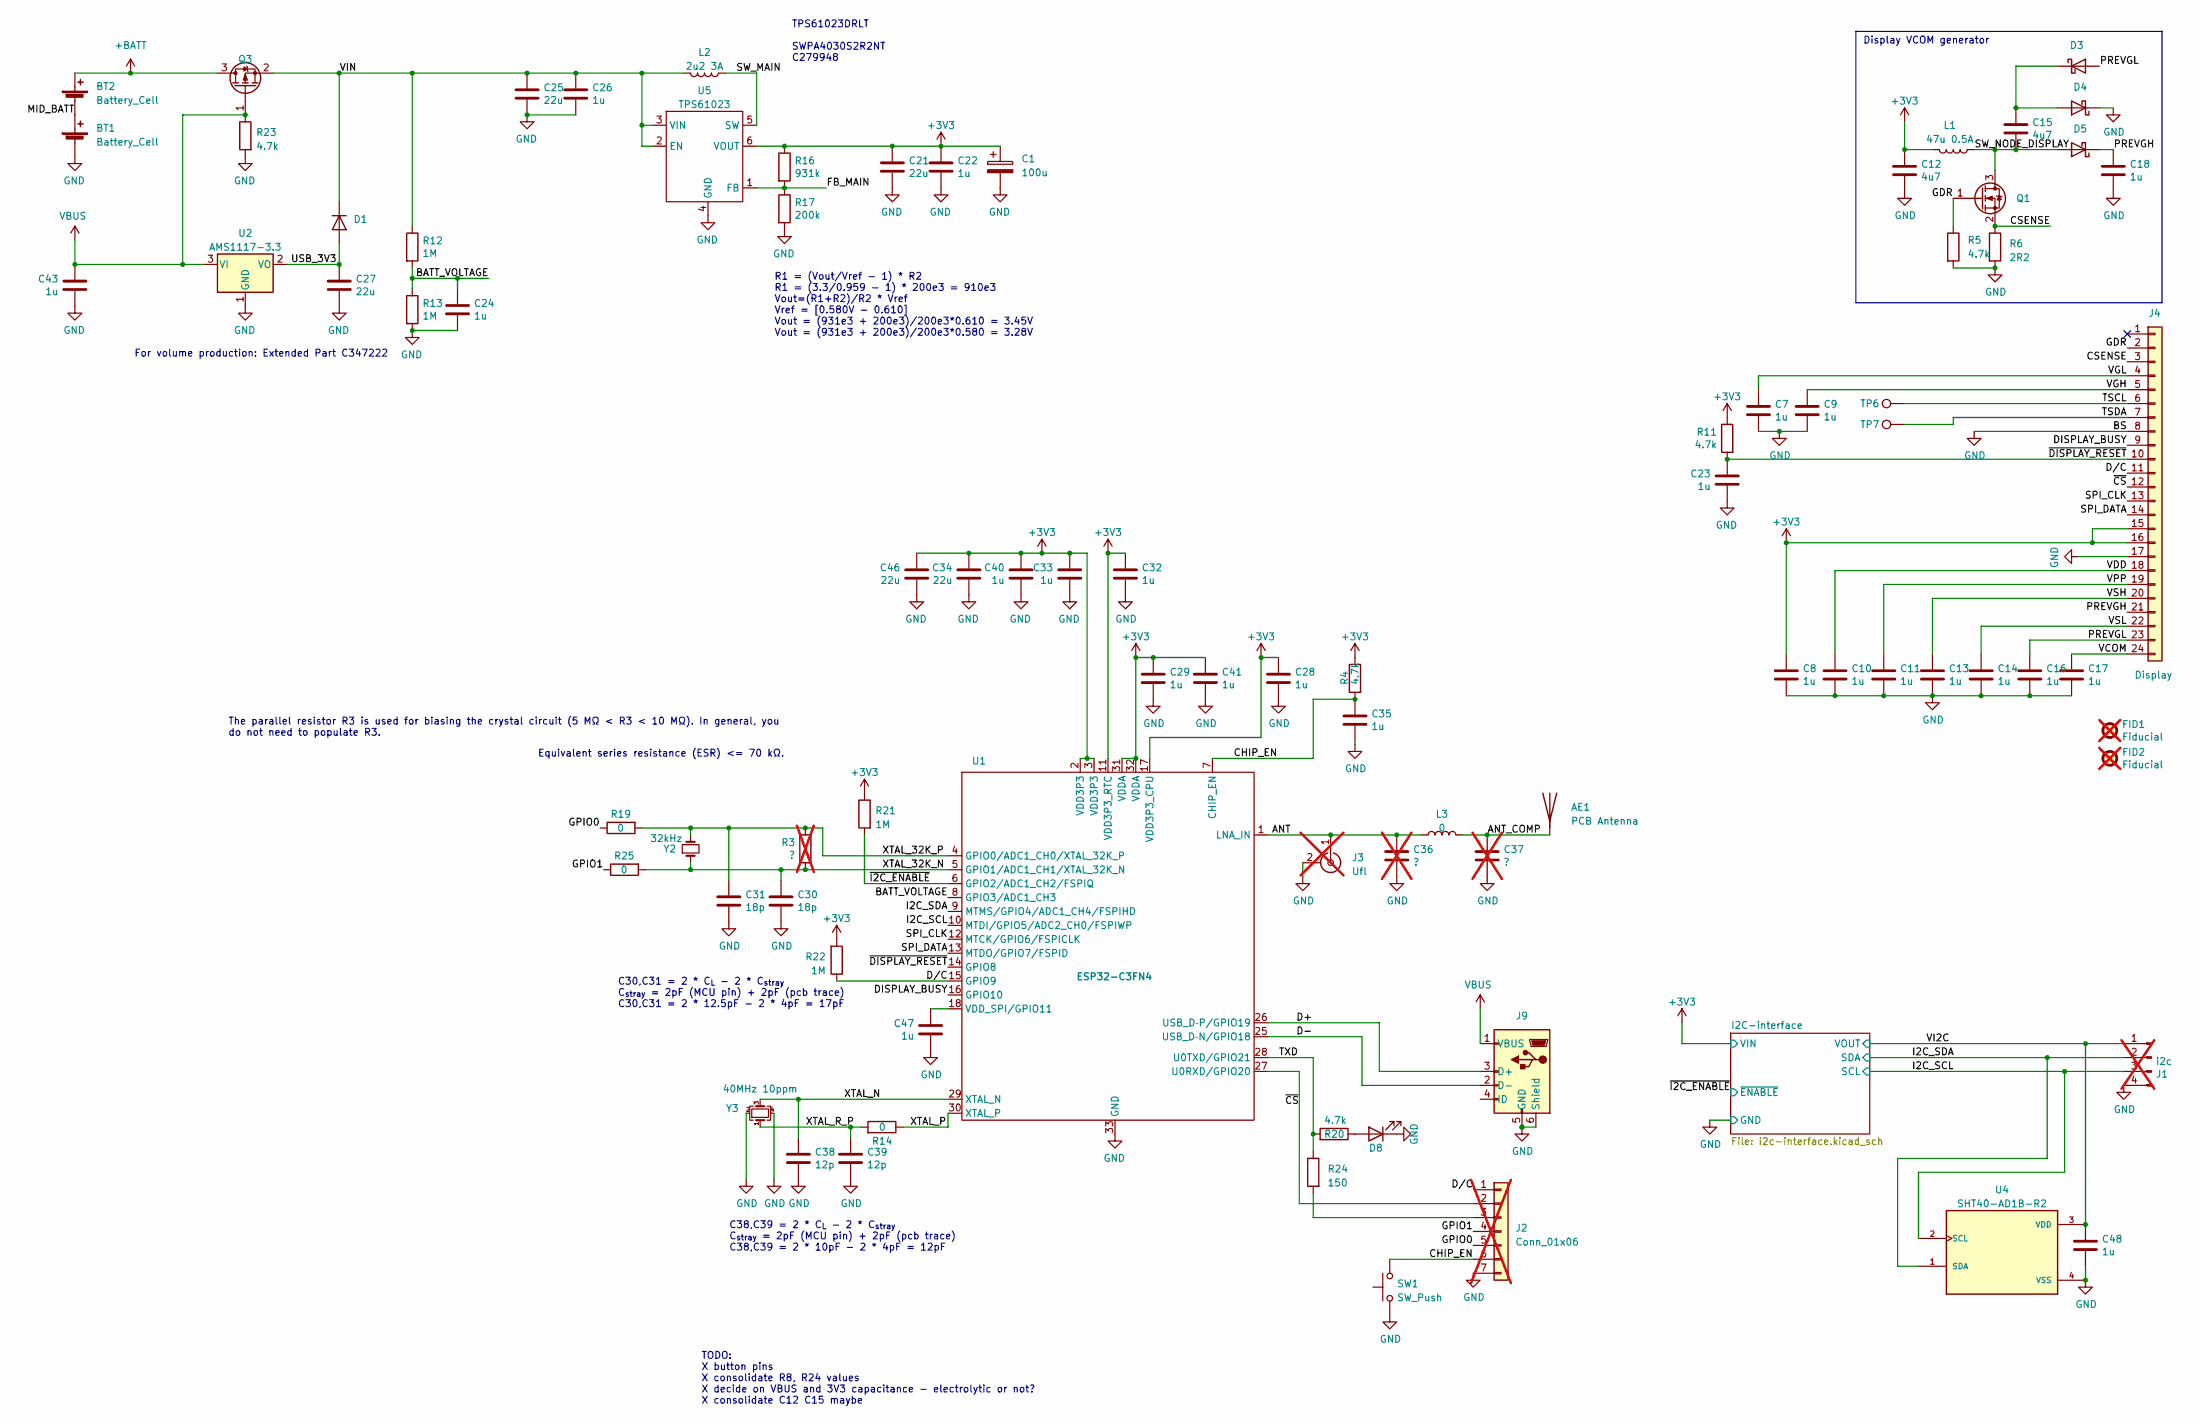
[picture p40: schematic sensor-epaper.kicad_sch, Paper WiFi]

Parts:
AE1: PCB Antenna; Texas_SWRA117D_2.4GHz_Left
BT1, BT2: Battery_Cell; AA_KEYCO_53_SMD; PartNo 53
C1: 100u; CP_EIA-3528-15_AVX-H; LCSC C16133
C7, C8, C9, C10, C11, C13, C14, C16, C17, C18, C22, C23, C24, C26, C28, C29, C32, C33, C35, C40, C41, C43, C47, C48: 1u; C_0402_1005Metric; LCSC C52923
C12, C15: 4u7; C_0603_1608Metric; LCSC C19666
C21, C25, C27: 22u; C_0603_1608Metric; PartNo CL10A226MP8NUNE; LCSC C60077
C30, C31: 18p; C_0402_1005Metric; LCSC C33149
C34, C46: 22u; C_0603_1608Metric; LCSC C60077
C36, C37: ?; C_0402_1005Metric; not fitted
C38, C39: 12p; C_0402_1005Metric; LCSC C106201
D1: 2CZ4007; D_SOD-123; LCSC C85712
D3, D4, D5: MBR0530; D_SOD-123; LCSC C8598
D8: LED; LED_0603_1608Metric
FID1, FID2: Fiducial; Fiducial_1mm_Mask2mm; not fitted
J1: i2c; PinHeader_1x04_P1.27mm_Vertical_SMD_Pin1Right; not fitted
J2: Conn_01x06; PinHeader_1x07_P2.54mm_Vertical; not fitted
J3: Ufl; U.FL_Hirose_U.FL-R-SMT-1_Vertical; not fitted
J4: Display; SFV24R-4STE1HLF; PartNo SFV24R-4STE1HLF; LCSC C262643
J9: USB micro; XKB_U254-051T-4BH83-F1S; PartNo U254-051T-4BH83-S1S; LCSC C319160
L1: 47u 0.5A; L_Taiyo-Yuden_NR-40xx; PartNo CKCS4030-47uH/M; LCSC C354593
L2: 2u2 3A; L_Taiyo-Yuden_NR-40xx; PartNo SWPA4030S2R2NT; LCSC C279948
L3: 0; L_0402_1005Metric; LCSC C17168
Q1: Q_NMOS_GSD; SOT-23; LCSC C699302
Q3: NX2301P; SOT-23; PartNo NX2301P,215; LCSC C15127
R3: ?; R_0402_1005Metric; not fitted
R4, R5, R11, R20, R23: 4.7k; R_0603_1608Metric; LCSC C23162
R6: 2R2; R_0603_1608Metric; LCSC C22939
R12, R13, R21, R22: 1M; R_0603_1608Metric; LCSC C22935
R14, R19, R25: 0; R_0402_1005Metric; LCSC C17168
R16: 931k; R_0603_1608Metric; LCSC C322030
R17: 200k; R_0603_1608Metric; LCSC C25811
R24: 150; R_0603_1608Metric; LCSC C22808
SW1: SW_Push; SHOUHAN_TS24CA; PartNo TS24CA; LCSC C393942
TP6, TP7: TestPoint; TestPoint_Pad_D1.5mm
U1: ESP32-C3FN4; QFN-32-1EP_5x5mm_P0.5mm_EP3.7x3.7mm_ThermalVias; LCSC C2858491
U2: AMS1117-3.3; SOT-223-3_TabPin2; LCSC C6186
U4: SHT40-AD1B-R2; Sensirion_SHT40-AD1B-R2
U5: TPS61023; SOT-363_SC-70-6; PartNo TPS61023; LCSC C919459
Y2: 32kHz; Crystal_SMD_2012-2Pin_2.0x1.2mm; PartNo ECS-.327-12.5-12R-TR
Y3: 40MHz 10ppm; Crystal_SMD_2016-4Pin_2.0x1.6mm; PartNo ECS-400-10-37B-CKY-TR

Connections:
+3V3: C1.1, C8.1, C12.1, C21.1, C22.1, C28.1, C29.1, C32.1, C33.1, C34.1, C40.1, C41.1, C46.1, J4.15, J4.16, L1.1, R4.1, R11.1, R16.1, R21.1, R22.2, U1.2 (VDD3P3), U1.3 (VDD3P3), U1.11 (VDD3P3_RTC), U1.17 (VDD3P3_CPU), U1.31 (VDDA), U1.32 (VDDA), U5.6 (VOUT); also elsewhere on the board
+BATT: BT2.1 (+), Q3.3 (D)
/ANT: C36.1, J3.1 (In), L3.1, U1.1 (LNA_IN)
/ANT_COMP: AE1.1 (A), C37.1, L3.2
/BATT_VOLTAGE: C24.1, R12.2, R13.1, U1.8 (GPIO3/ADC1_CH3)
/CHIP_EN: C35.1, J2.6, R4.2, SW1.2, U1.7 (CHIP_EN)
/CSENSE: J4.3, Q1.2 (S), R6.1
/D+: J9.3 (D+), U1.26 (USB_D­P/GPIO19)
/D-: J9.2 (D-), U1.25 (USB_D­N/GPIO18)
/DISPLAY_BUSY: J4.9, U1.16 (GPIO10)
/D/C: J2.1, J4.11, R22.1, U1.15 (GPIO9)
/FB_MAIN: R16.2, R17.1, U5.1 (FB)
/GDR: J4.2, Q1.1 (G), R5.1
/GPIO0: J2.5, R19.1
/GPIO1: J2.4, R25.1
/I2C_SCL: J1.3, U1.10 (MTDI/GPIO5/ADC2_CH0/FSPIWP), U4.2 (SCL); also elsewhere on the board
/I2C_SDA: J1.2, U1.9 (MTMS/GPIO4/ADC1_CH4/FSPIHD), U4.1 (SDA); also elsewhere on the board
/MID_BATT: BT1.1 (+), BT2.2 (-)
/PREVGH: C18.1, D5.1 (K), J4.21
/PREVGL: C16.1, D3.2 (A), J4.23
/SPI_CLK: J4.13, U1.12 (MTCK/GPIO6/FSPICLK)
/SPI_DATA: J4.14, U1.13 (MTDO/GPIO7/FSPID)
/SW_MAIN: L2.2, U5.5 (SW)
/SW_NODE_DISPLAY: C15.2, D5.2 (A), L1.2, Q1.3 (D)
/TSCL: J4.6, TP6.1
/TSDA: J4.7, TP7.1
/TXD: R20.2, R24.1, U1.28 (U0TXD/GPIO21)
/USB_3V3: C27.1, D1.2 (A), U2.2 (VO)
/VCOM: C17.1, J4.24
/VDD: C10.1, J4.18
/VGH: C9.1, J4.5
/VGL: C7.1, J4.4
/VI2C: C48.1, J1.1, U4.3 (VDD); also elsewhere on the board
/VIN: C25.1, C26.1, D1.1 (K), L2.1, Q3.2 (S), R12.1, U5.2 (EN), U5.3 (VIN)
/VPP: C11.1, J4.19
/VSH: C13.1, J4.20
/VSL: C14.1, J4.22
/XTAL_32K_N: C30.1, R3.2, R25.2, U1.5 (GPIO1/ADC1_CH1/XTAL_32K_N), Y2.1
/XTAL_32K_P: C31.1, R3.1, R19.2, U1.4 (GPIO0/ADC1_CH0/XTAL_32K_P), Y2.2
/XTAL_N: C38.1, U1.29 (XTAL_N), Y3.3
/XTAL_P: R14.1, U1.30 (XTAL_P)
/XTAL_R_P: C39.1, R14.2, Y3.1
/~CS: J2.2, J4.12, U1.27 (U0RXD/GPIO20)
/~DISPLAY_RESET: C23.1, J4.10, R11.2, U1.14 (GPIO8)
/~I2C_ENABLE: R21.2, U1.6 (GPIO2/ADC1_CH2/FSPIQ); also elsewhere on the board
GND: BT1.2 (-), C1.2, C7.2, C8.2, C9.2, C10.2, C11.2, C12.2, C13.2, C14.2, C16.2, C17.2, C18.2, C21.2, C22.2, C23.2, C24.2, C25.2, C26.2, C27.2, C28.2, C29.2, C30.2, C31.2, C32.2, C33.2, C34.2, C35.2, C36.2, C37.2, C38.2, C39.2, C40.2, C41.2, C43.2, C46.2, C47.2, C48.2, D4.1 (K), D8.1 (K), J1.4, J2.7, J3.2 (Ext), J4.8, J4.17, J9.5 (GND), J9.6 (Shield), R5.2, R6.2, R13.2, R17.2, R23.2, SW1.1, U1.33 (GND), U2.1 (GND), U4.4 (VSS), U5.4 (GND), Y3.2, Y3.4
unnamed: C15.1, D3.1 (K), D4.2 (A)
unnamed: D8.2 (A), R20.1
unnamed: J2.3, R24.2
unnamed: C47.1, U1.18 (VDD_SPI/GPIO11)
VBUS: C43.1, J9.1 (VBUS), Q3.1 (G), R23.1, U2.3 (VI)

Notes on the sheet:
R1 = (Vout/Vref - 1) * R2 R1 = (3.3/0.959 - 1) * 200e3 = 910e3 Vout=(R1+R2)/R2 * Vref Vref = [0.580V - 0.610] Vout = (931e3 + 200e3)/200e3*0.610 = 3.45V Vout = (931e3 + 200e3)/200e3*0.580 = 3.28V
Equivalent series resistance (ESR) <= 70 kΩ.
TODO: X button pins X consolidate R8, R24 values X decide on VBUS and 3V3 capacitance - electrolytic or not? X consolidate C12 C15 maybe
For volume production: Extended Part C347222
The parallel resistor R3 is used for biasing the crystal circuit (5 MΩ < R3 < 10 MΩ). In general, you do not need to populate R3.
Display VCOM generator
TPS61023DRLT SWPA4030S2R2NT C279948
C30,C31 = 2 * C_{L} - 2 * C_{stray} C_{stray} = 2pF (MCU pin) + 2pF (pcb trace) C30,C31 = 2 * 12.5pF - 2 * 4pF = 17pF
C38,C39 = 2 * C_{L} - 2 * C_{stray} C_{stray} = 2pF (MCU pin) + 2pF (pcb trace) C38,C39 = 2 * 10pF - 2 * 4pF = 12pF

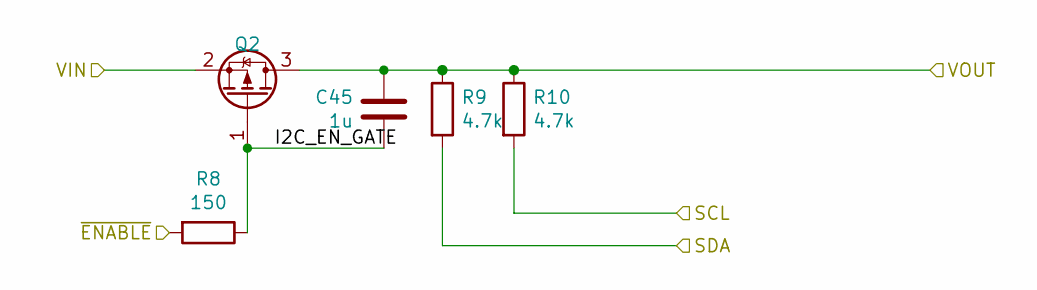
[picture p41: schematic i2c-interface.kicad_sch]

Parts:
C45: 1u; C_0402_1005Metric; LCSC C52923
Q2: NX2301P; SOT-23; PartNo NX2301P,215; LCSC C15127
R8: 150; R_0603_1608Metric; LCSC C22808
R9, R10: 4.7k; R_0603_1608Metric; LCSC C23162

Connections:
+3V3: Q2.2 (S); also elsewhere on the board
/I2C-interface/I2C_EN_GATE: C45.2, Q2.1 (G), R8.1
/I2C_SCL: R10.2; also elsewhere on the board
/I2C_SDA: R9.2; also elsewhere on the board
/VI2C: C45.1, Q2.3 (D), R9.1, R10.1; also elsewhere on the board
/~I2C_ENABLE: R8.2; also elsewhere on the board

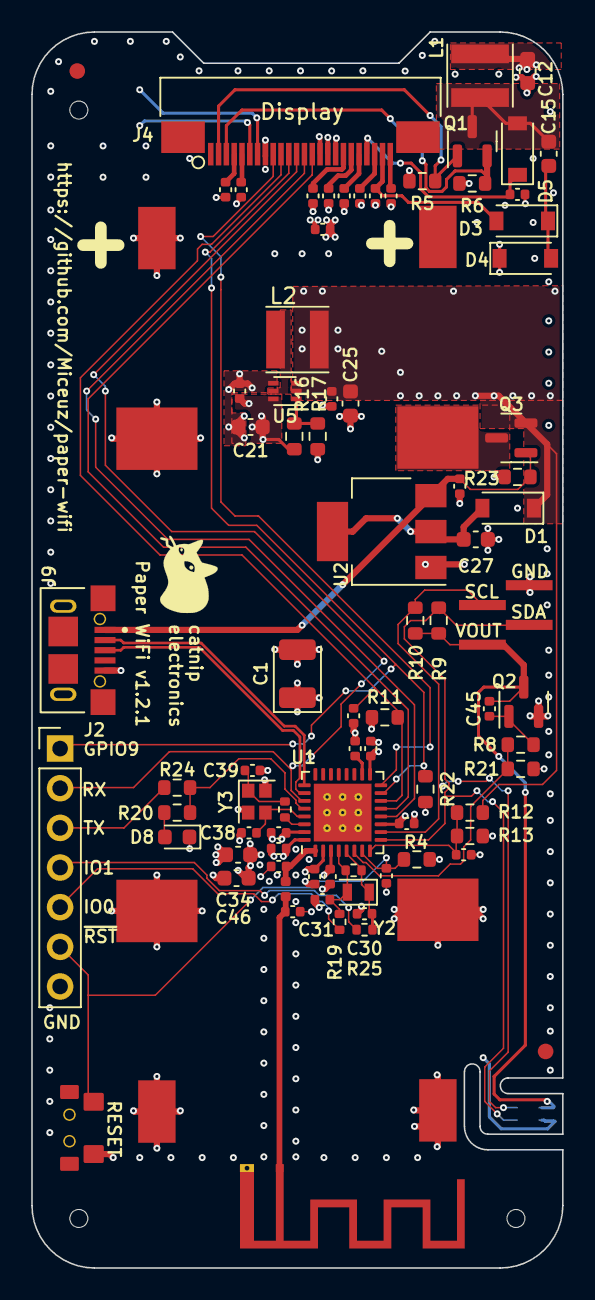
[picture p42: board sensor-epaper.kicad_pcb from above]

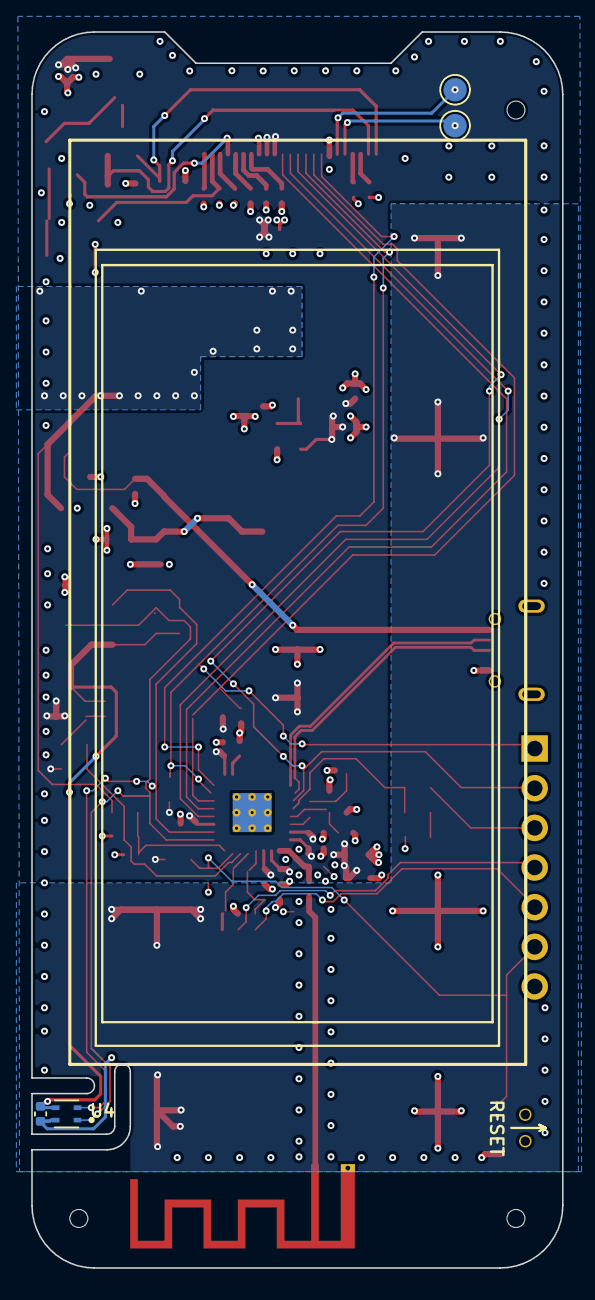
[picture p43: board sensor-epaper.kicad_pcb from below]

Board: 4 copper layers, 34.0 x 79.2 mm, 91 parts (4 on the bottom side), 52 nets.

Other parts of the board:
H6, H6#2, H6#3: ToolingHole; JLC_ToolingHole

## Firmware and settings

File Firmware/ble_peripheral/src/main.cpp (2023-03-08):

#include <Arduino.h>
#include <BLE2902.h>
#include <BLEDevice.h>
#include <BLEServer.h>
#include <BLEUtils.h>
#include <SensirionI2CSht4x.h>

#define I2C_ENABLE 2
SensirionI2CSht4x sht4x;
float temperature = 0;
float humidity = 0;

#define SERVICE_UUID "4fafc201-1fb5-459e-8fcc-c5c9c331914b"
#define SERVICE_UUID_16 "4faf"
#define TEMPERATURE_UUID "beb5483e-36e1-4688-b7f5-ea07361b26a8"
#define HUMIDITY_UUID "c7d9f4d4-7c8d-4da4-b3db-2f22c8b793ba"

BLEServer *pServer = NULL;

BLECharacteristic *tempCharacteristic = NULL;
BLECharacteristic *humCharacteristic = NULL;

BLEAdvertising *pAdvertising;

class ServerCallbacks : public BLEServerCallbacks {
  void onConnect(BLEServer *pServer, esp_ble_gatts_cb_param_t *param) {
    Serial.println("Connected");

    uint16_t intervalMin = 3 / 1.25e-3;
    uint16_t intervalMax = 4 / 1.25e-3;
    uint16_t timeout = 20 / 10e-3;
    uint16_t latency = 0;

    pServer->updateConnParams(param->connect.remote_bda, intervalMin,
                              intervalMax, latency, timeout);
  }

  void onDisconnect(BLEServer *pServer) {
    Serial.println("Disconnected");
    BLEDevice::startAdvertising();
  }
};

void setup() {
  pinMode(I2C_ENABLE, OUTPUT);
  digitalWrite(I2C_ENABLE, LOW);
  Wire.begin();
  sht4x.begin(Wire);

  Serial.begin(115200);
  BLEDevice::init("PaperWiFi");
  pServer = BLEDevice::createServer();
  pServer->setCallbacks(new ServerCallbacks());

  BLEService *pService = pServer->createService(SERVICE_UUID);

  tempCharacteristic = pService->createCharacteristic(
      TEMPERATURE_UUID,
      BLECharacteristic::PROPERTY_READ | BLECharacteristic::PROPERTY_NOTIFY);
  tempCharacteristic->setValue(temperature);
  tempCharacteristic->addDescriptor(new BLE2902());
  BLEDescriptor *pDescriptor = new BLEDescriptor(BLEUUID((uint16_t)0x2901));
  pDescriptor->setValue("Temperature (Celsius)");
  tempCharacteristic->addDescriptor(pDescriptor);

  humCharacteristic = pService->createCharacteristic(
      HUMIDITY_UUID,
      BLECharacteristic::PROPERTY_READ | BLECharacteristic::PROPERTY_NOTIFY);
  humCharacteristic->setValue(humidity);
  humCharacteristic->addDescriptor(new BLE2902());
  BLEDescriptor *pDescriptor2 = new BLEDescriptor(BLEUUID((uint16_t)0x2901));
  pDescriptor2->setValue("Humidity (%)");
  humCharacteristic->addDescriptor(pDescriptor2);

  pService->start();

  pAdvertising = pServer->getAdvertising();
  pAdvertising->setAdvertisementType(ADV_TYPE_NONCONN_IND);
  pAdvertising->setMinInterval(1 / 0.625e-3);
  pAdvertising->setMaxInterval(2 / 0.625e-3);
  pAdvertising->addServiceUUID(SERVICE_UUID);
  pAdvertising->setScanResponse(false);
  pAdvertising->setMinPreferred(0x0);
  pAdvertising->setMinPreferred(0x12);

  BLEDevice::startAdvertising();
}

void AddFloat(String &s, float f) {
  char const *p = reinterpret_cast<char *>(&f);
  s += *p++;
  s += *p++;
  s += *p++;
  s += *p++;
}

void DecodeSensorData(String s, float &t, float &h) {
  char *sp = const_cast<char *>(s.c_str());
  sp += 2;
  float *f = reinterpret_cast<float *>(sp);
  t = *f;
  h = *(f+1);
}

void loop() {
  uint16_t error;
  char errorMessage[256];
  error = sht4x.measureHighPrecision(temperature, humidity);
  if (error) {
    Serial.print("Error trying to execute measureHighPrecision(): ");
    errorToString(error, errorMessage, 256);
    Serial.println(errorMessage);
  } else {
    Serial.print("Temperature:");
    Serial.print(temperature);
    Serial.print("\t");
    Serial.print("Humidity:");
    Serial.println(humidity);

    tempCharacteristic->setValue(temperature);
    tempCharacteristic->notify();

    humCharacteristic->setValue(humidity);
    humCharacteristic->notify();

    BLEAdvertisementData data;
    String s = "";
    // manufacturer code (0x02E5 for Espressif)
    s += (char)0xE5;
    s += (char)0x02;

    AddFloat(s, temperature);
    AddFloat(s, humidity);
    data.setName("PaperWifi");
    data.setFlags(ESP_BLE_ADV_FLAG_BREDR_NOT_SPT | ESP_BLE_ADV_FLAG_GEN_DISC);
    data.setCompleteServices(BLEUUID(SERVICE_UUID_16));
    data.setManufacturerData(s.c_str());

    pAdvertising->setAdvertisementData(data);
  }

  delay(3000);
}

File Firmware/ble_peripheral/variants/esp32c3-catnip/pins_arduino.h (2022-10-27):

#ifndef Pins_Arduino_h
#define Pins_Arduino_h

#include "soc/soc_caps.h"
#include <stdint.h>

#define EXTERNAL_NUM_INTERRUPTS 22
#define NUM_DIGITAL_PINS 22
#define NUM_ANALOG_INPUTS 6

static const uint8_t LED_BUILTIN = SOC_GPIO_PIN_COUNT + 8;
#define BUILTIN_LED LED_BUILTIN // backward compatibility
#define LED_BUILTIN LED_BUILTIN
#define RGB_BUILTIN LED_BUILTIN
#define RGB_BRIGHTNESS 64

#define analogInputToDigitalPin(p)                                             \
  (((p) < NUM_ANALOG_INPUTS) ? (analogChannelToDigitalPin(p)) : -1)
#define digitalPinToInterrupt(p) (((p) < NUM_DIGITAL_PINS) ? (p) : -1)
#define digitalPinHasPWM(p) (p < EXTERNAL_NUM_INTERRUPTS)

static const uint8_t TX = 21;
static const uint8_t RX = 20;

static const uint8_t SDA = 4;
static const uint8_t SCL = 5;

static const uint8_t SS = 20;
static const uint8_t MOSI = 7;
static const uint8_t MISO = -1;
static const uint8_t SCK = 6;

static const uint8_t A0 = 0;
static const uint8_t A1 = 1;
static const uint8_t A2 = 2;
static const uint8_t A3 = 3;
static const uint8_t A4 = 4;
static const uint8_t A5 = 5;

#endif /* Pins_Arduino_h */

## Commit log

2022-01-22 Add mechanical stuff - drawings of case and test assemblies
    [EW0213F9 v1 batdangt.step, EW0213F9 v1 batkorp.step, EW0213F9 v1 fronsnuk.step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]
2022-10-27 Implement fixes for v1.0.0 board: * Fixed mirrored display connector * Fixed wrong button pinout * Remove CS from GPIO11 which is VDD_SPI after all, add a requisite cap * Add tantallum bulk cap, add 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
    [i2c-interface.kicad_sch, sensor-epaper.kicad_pcb, sensor-epaper.kicad_sch]
2022-10-27 Add more documentation
    [ESP32-C3.dxf]
2022-11-09 Shuffle stuff on User Comments layer, hunt kicad format changes
    [sensor-epaper.kicad_pcb]
2022-11-09 Add case
    [Waveshare 2.13 (D) E-ink - Flat.stp, Waveshare 2.13 (D) E-ink - Reverse Mount.stp, enclosure-Body.stl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]
2022-11-09 Remove autogenerated file
    [sensor-epaper-F_Silkscreen.dxf]
2022-12-05 Add deep sleep current
2022-12-05 Tidy up mechanical folder
    [ESP32-C3.dxf, EW0213F9 v1 batdangt.step, EW0213F9 v1 batkorp.step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]
2022-12-05 Add cutout in the PCB to decouple SHT40, fix GND connection
    [i2c-interface.kicad_sch, sensor-epaper.kicad_pcb, sensor-epaper.kicad_sch]
2022-12-06 Refactor soil moisture sensor example firmware a bit
2022-12-14 Refactor code more, fix some corner cases
    [main.ino, mqtt.cpp]
2022-12-15 Work around AP creation issues that still manifest in some cases
    [main.ino]
2022-12-15 Migrate previous changes to humidity sensor example
2022-12-19 Fix a bug where temperature units were printed as string while they are char
2022-12-20 Add latest fixes and features to humidity display firmware
    [main.ino, mqtt.cpp]
2022-12-24 Add a silkscreen for git repo
    [sensor-epaper.kicad_pcb]
2023-01-04 Change DC/DC regulator to TPS61023 as previous one is out of stock. Change L1 and R6 to accomodate another display as previous one will be end of life soon
    [i2c-interface.kicad_sch, sensor-epaper.kicad_pcb, sensor-epaper.kicad_sch]
2023-02-18 Put correct resistor into Dc/Dc converters divider. Fix SC70 footprint
    [i2c-interface.kicad_sch, sensor-epaper.kicad_pcb, sensor-epaper.kicad_sch]
2023-03-07 Fix 3d model rotation
    [sensor-epaper.kicad_pcb]
2023-03-07 Fix antenna trace so it's 50 Ohm
    [sensor-epaper.kicad_pcb]
2023-09-20 Impove soil moisture sensor example - new display, no debug delay, better batterylife
